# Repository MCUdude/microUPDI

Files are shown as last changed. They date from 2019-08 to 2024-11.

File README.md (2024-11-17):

# microUPDI
DIY UPDI programmer with open-source hardware.
**Available for purchase at my [Tindie store](https://www.tindie.com/products/MCUdude/microupdi-programmer/)!**

## Hardware
The microUPDI programmer is based on the [Sparkfun Pro Micro 5V/16MHz board](https://www.sparkfun.com/products/12640) (cheaper knock-offs also compatible) together with a daughterboard. This makes the programmer both cheap and easy to assemble.

    

## Features
* A 6-pin UPDI programming connector
  - UPDI interface for programming and debugging
  - Serial interface for communicating with the target over UART
* Voltage selection jumper where you can choose between 5V, 3.3V, or no target power
* RXD and TXD LEDs
* Buffered RXD and TXD lines for high-impedance inputs and low-impedance outputs
* Status LED
  - Power up -> LED is briefly lid
  - Normal operation -> LED is not lid
  - Programming -> Activity indicator
* Small in size (18.3mm x 49.6mm)
* **Open source hardware!**

## Firmware
To flash the Pro Micro with mEDBG firmware you'll have to install a hardware package to Arduino IDE.

#### Boards Manager Installation
* Open the Arduino IDE
* Open the **File > Preferences** menu item.
* Enter the following URL in **Additional Boards Manager URLs**:
    ```
    https://mcudude.github.io/microUPDIcore/package_MCUdude_microUPDIcore_index.json
    ```
* Separate the URLs using a comma ( **,** ) if you have more than one URL
* Open the **Tools > Board > Boards Manager...** menu item.
* Wait for the platform indexes to finish downloading.
* Scroll down until you see the **microUPDI flash tool** entry and click on it.
* Make sure you have selected the latest version.
* Click **Install**.
* After installation is complete close the **Boards Manager** window.

#### Manual Installation
Visit [microUPDIcore](https://github.com/MCUdude/microUPDIcore), and click on the "Download ZIP" button. Extract the ZIP file, and move the extracted folder to the location "**~/Documents/Arduino/hardware**". Create the "hardware" folder if it doesn't exist.
Open Arduino IDE and a new category in the boards menu called "microUPDI Firmware Uploader" will show up.

### Flashing the Arduino Pro Micro
* Select **microUPDI Firmware Uploader** from the boards menu.
* Connect your Arduino Pro Micro hardware to your computer through a micro USB cable.
* Click on the upload button. This will upload some pre-built binaries, and the code in the current sketch isn't touched at all.
* The IDE will now automatically try to reset the Pro Micro and load it with new firmware.
  - If you've already flashed your Pro Micro with mEDBG firmware and want to upgrade or re-flash it you will most likely encounter issues with the auto reset functionality and uploading will fail. All you have to do is click *Upload* in Arduino IDE and then manually reset the Pro Micro within about three seconds. Resetting can be done by shorting out pin 5 and 6 on the 32U4 ISP header for a brief second with a tweezer, screwdriver, or jumper wire. If you need a longer timeout delay, you can quickly reset the 32U4 twice. This will make the board stay in bootloader mode for an extended period, usually about 8 seconds. Read more about manual bootloader entry [here](https://learn.sparkfun.com/tutorials/pro-micro--fio-v3-hookup-guide/troubleshooting-and-faq#ts-reset).
* After uploading is finished you may get an error telling you there's **content mismatch from flash address 0x7000**. This is normal and is to be expected due to the protected bootloader area, and the standard Pro Micro bootloader is retained.
* Congratulations, you now have a working UPDI programmer!

### Usage
After the Pro Micro is flashed with mEDBG firmware it will present itself to the computer as an **mEDBG CMSIS-DAP** device. In Atmel Studio it will show up as a generic mEDBG device, while in Arduino IDE it will show up as an **Arduino UNO WiFi Rev2*.

If you're using the microUPDI programmer with [megaTinyCore](https://github.com/SpenceKonde/megaTinyCore) you just select the *Xplained Mini (mEDBG, debug chip: ATmega32u4)* option in the Programmers menu. For [MegaCoreX](https://github.com/MCUdude/MegaCoreX) it's *Atmel mEDBG (microUPDI)*.

Here's an example command on how you can communicate with an ATmega4809 through Avrdude:
```
$ avrdude -C avrdude.conf -v -p atmega4809 -c xplainedmini_updi
```

### Pinout
The UPDI pinout is based on the standard 6-pin ISP pinout. It's reverse insertion tolerant, just like the "old" ISP interface. It's also compatible with the Atmel ICE UPDI pinout. This means if you've designed a board to work with this (microUPDI) programmer, you can safely connect and use an Atmel ICE programmer without damaging your board or the ICE programmer.<br/>
**Note that the RXD and TXD lines are swapped on the target.**

*Click to enlarge:*



### Tinkering with the EEPROM content
The EEPROM content of the microUPDI content contains things like serial number, kit name, manufacturer string, target device ID, and name. The content is loosely documented in [this Avrfreaks forum post](https://www.avrfreaks.net/s/topic/a5C3l000000UkjBEAS/t192342?comment=P-1635680).

<details>
<summary><b>mEDBG EEPROM mapping</b></summary>

```
MEDBG_CONFIG_SERIAL_NUMBER_BANK = 0x00
MEDBG_CONFIG_SERIAL_NUMBER_ADDRESS = 0x04
MEDBG_CONFIG_SERIAL_NUMBER_LEN = 20
 
MEDBG_CONFIG_KIT_NAME_BANK = 0x00
MEDBG_CONFIG_KIT_NAME_ADDRESS = 0x18
MEDBG_CONFIG_KIT_NAME_LEN_MAX = 50
 
MEDBG_CONFIG_MANUFACTURER_NAME_BANK = 0x00
MEDBG_CONFIG_MANUFACTURER_NAME_ADDRESS = 0x4A
MEDBG_CONFIG_MANUFACTURER_NAME_LEN_MAX = 50
 
MEDBG_CONFIG_TARGET_NAME_BANK = 0x00
MEDBG_CONFIG_TARGET_NAME_ADDRESS = 0x7C
MEDBG_CONFIG_TARGET_NAME_LEN_MAX = 30
 
MEDBG_CONFIG_FIRE_BANK = 0x00
MEDBG_CONFIG_FIRE_ADDRESS = 0xFE
MEDBG_CONFIG_FIRE_LEN = 1
 
MEDBG_CONFIG_FIRE_ISPDW_VALUE = 0xFF
MEDBG_CONFIG_FIRE_SWD_VALUE = 0xFE
MEDBG_CONFIG_FIRE_TPI_VALUE = 0XFD
MEDBG_CONFIG_FIRE_UPDI_VALUE = 0xFC
 
MEDBG_CONFIG_SUFFER_BANK = 0x01
MEDBG_CONFIG_SUFFER_ADDRESS = 0x220
MEDBG_CONFIG_SUFFER_LEN = 1
```

</details>

It's very easy to use Avrdude (8.0 or newer is highly recommended) to change the content. Simply connect an ISP programmer, connect it to the ISP connector on the underside of the microUPDI programmer (a 6-pin male header can be press-fitted), and run Avrdude. In the example below I'm using the USBasp programmer with Avrdude 8.0 to view and modify the EEPROM content:

```
$ avrdude -c usbasp -p atmega32u4 -t

avrdude> read eeprom 0 256 # Read 256 bytes from EEPROM starting from address 0
Reading | ################################################## | 100% 0.09 s 
0000  ff ff ff ff 4d 49 43 52  4f 55 50 44 49 50 52 4f  |....MICROUPDIPRO|
0010  47 52 41 4d 4d 45 52 58  6d 69 63 72 6f 55 50 44  |GRAMMERXmicroUPD|
0020  49 20 70 72 6f 67 72 61  6d 6d 65 72 00 ff ff ff  |I programmer....|
0030  ff ff ff ff ff ff ff ff  ff ff ff ff ff ff ff ff  |................|
0040  ff ff ff ff ff ff ff ff  ff ff 4d 69 63 72 6f 63  |..........Microc|
0050  68 69 70 00 ff ff ff ff  ff ff ff ff ff ff ff ff  |hip.............|
0060  ff ff ff ff ff ff ff ff  ff ff ff ff ff ff ff ff  |................|
0070  ff ff ff ff ff ff ff ff  ff ff ff ff 41 54 6d 65  |............ATme|
0080  67 61 34 38 30 39 00 ff  ff ff ff ff ff ff ff ff  |ga4809..........|
0090  ff ff ff ff ff ff ff ff  ff ff 00 1e 96 51 ff ff  |.............Q..|
00a0  ff ff ff ff ff ff ff ff  ff ff ff ff ff ff ff ff  |................|
00b0  ff ff ff ff ff ff ff ff  ff ff ff ff ff ff ff ff  |................|
00c0  ff ff ff ff ff ff ff ff  ff ff ff ff ff ff ff ff  |................|
00d0  ff ff ff ff ff ff ff ff  ff ff ff ff ff ff ff ff  |................|
00e0  ff ff ff ff ff ff ff ff  ff ff ff ff ff ff ff ff  |................|
00f0  ff ff ff ff ff ff ff ff  ff ff ff ff ff ff fc ff  |................|

avrdude> write eeprom 4 20 0xff ... # Wipe the existing serial number by writing 20 0xff bytes to the EEPROM, starting from address 4
Caching | ################################################## | 100% 0.00 s

avrdude> read eeprom 0 256
Reading | ################################################## | 100% 0.00 s 
0000  ff ff ff ff ff ff ff ff  ff ff ff ff ff ff ff ff  |................|
0010  ff ff ff ff ff ff ff ff  6d 69 63 72 6f 55 50 44  |........microUPD|
0020  49 20 70 72 6f 67 72 61  6d 6d 65 72 00 ff ff ff  |I programmer....|
0030  ff ff ff ff ff ff ff ff  ff ff ff ff ff ff ff ff  |................|
0040  ff ff ff ff ff ff ff ff  ff ff 4d 69 63 72 6f 63  |..........Microc|
0050  68 69 70 00 ff ff ff ff  ff ff ff ff ff ff ff ff  |hip.............|
0060  ff ff ff ff ff ff ff ff  ff ff ff ff ff ff ff ff  |................|
0070  ff ff ff ff ff ff ff ff  ff ff ff ff 41 54 6d 65  |............ATme|
0080  67 61 34 38 30 39 00 ff  ff ff ff ff ff ff ff ff  |ga4809..........|
0090  ff ff ff ff ff ff ff ff  ff ff 00 1e 96 51 ff ff  |.............Q..|
00a0  ff ff ff ff ff ff ff ff  ff ff ff ff ff ff ff ff  |................|
00b0  ff ff ff ff ff ff ff ff  ff ff ff ff ff ff ff ff  |................|
00c0  ff ff ff ff ff ff ff ff  ff ff ff ff ff ff ff ff  |................|
00d0  ff ff ff ff ff ff ff ff  ff ff ff ff ff ff ff ff  |................|
00e0  ff ff ff ff ff ff ff ff  ff ff ff ff ff ff ff ff  |................|
00f0  ff ff ff ff ff ff ff ff  ff ff ff ff ff ff fc ff  |................|

avrdude> write eeprom 4 "MYSERIALNUMBER" # Write new serial number to EEPROM, starting from address 4
Caching | ################################################## | 100% 0.00 s

avrdude> read eeprom 0 256
Reading | ################################################## | 100% 0.00 s 
0000  ff ff ff ff 4d 59 53 45  52 49 41 4c 4e 55 4d 42  |....MYSERIALNUMB|
0010  45 52 00 ff ff ff ff ff  6d 69 63 72 6f 55 50 44  |ER......microUPD|
0020  49 20 70 72 6f 67 72 61  6d 6d 65 72 00 ff ff ff  |I programmer....|
0030  ff ff ff ff ff ff ff ff  ff ff ff ff ff ff ff ff  |................|
0040  ff ff ff ff ff ff ff ff  ff ff 4d 69 63 72 6f 63  |..........Microc|
0050  68 69 70 00 ff ff ff ff  ff ff ff ff ff ff ff ff  |hip.............|
0060  ff ff ff ff ff ff ff ff  ff ff ff ff ff ff ff ff  |................|
0070  ff ff ff ff ff ff ff ff  ff ff ff ff 41 54 6d 65  |............ATme|
0080  67 61 34 38 30 39 00 ff  ff ff ff ff ff ff ff ff  |ga4809..........|
0090  ff ff ff ff ff ff ff ff  ff ff 00 1e 96 51 ff ff  |.............Q..|
00a0  ff ff ff ff ff ff ff ff  ff ff ff ff ff ff ff ff  |................|
00b0  ff ff ff ff ff ff ff ff  ff ff ff ff ff ff ff ff  |................|
00c0  ff ff ff ff ff ff ff ff  ff ff ff ff ff ff ff ff  |................|
00d0  ff ff ff ff ff ff ff ff  ff ff ff ff ff ff ff ff  |................|
00e0  ff ff ff ff ff ff ff ff  ff ff ff ff ff ff ff ff  |................|
00f0  ff ff ff ff ff ff ff ff  ff ff ff ff ff ff fc ff  |................|

avrdude> quit
Synching cache to device ... 
Writing | ################################################## | 100% 0.04 s 

Avrdude done.  Thank you.
```

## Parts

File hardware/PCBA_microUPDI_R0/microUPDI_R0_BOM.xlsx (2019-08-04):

Bill of Materials
Author: | MCUdude
Source from: | microUPDI.PrjPcb
Project name: | microUPDI.PrjPcb
Variant: | None
Revision: | R0
Creation date: | 04.08.2019
Quantity | Designator | Value | Manufacturer | Manufacturer Part Number | Manufacturer 2 | Manufacturer Part Number 2 | Description | Package | Notes
2 | C1, C2 | 1u |  |  |  |  | Cap Ceramic 0805 1u 16V Y5V | 0805 | Generic, choose one that meets spec
2 | C3, C4 | 100n |  |  |  |  | Cap Ceramic 0805 100n 50V X7R | 0805 | Generic, choose one that meets spec
1 | D1 |  |  |  |  |  | LED 0805 Green | 0805
2 | D2, D3 |  |  |  |  |  | LED 0805 Red | 0805
1 | IC1 |  |  | 1117-3.3 |  |  | Positive 3.3V regulator 1A SOT-223 | SOT-223 | Generic 1117-3.3
2 | IC3, IC4 |  |  | 74LVC1G125 |  |  | Singe Buffer with 3-State Output | SOT-353
1 | J1 |  |  |  |  |  | Header male straight 1x3
1 | J2 |  |  |  |  |  | Header male straight 2x3
3 | R1, R2, R5 | 1k |  |  |  |  | Resistor 0805 1k 1% | 0805 | Generic, choose one that meets spec
1 | R3 | 330R |  |  |  |  | Resistor 0805 330R 1% | 0805 | Generic, choose one that meets spec
1 | R4 | 10k |  |  |  |  | Resistor 0805 10k 1% | 0805 | Generic, choose one that meets spec

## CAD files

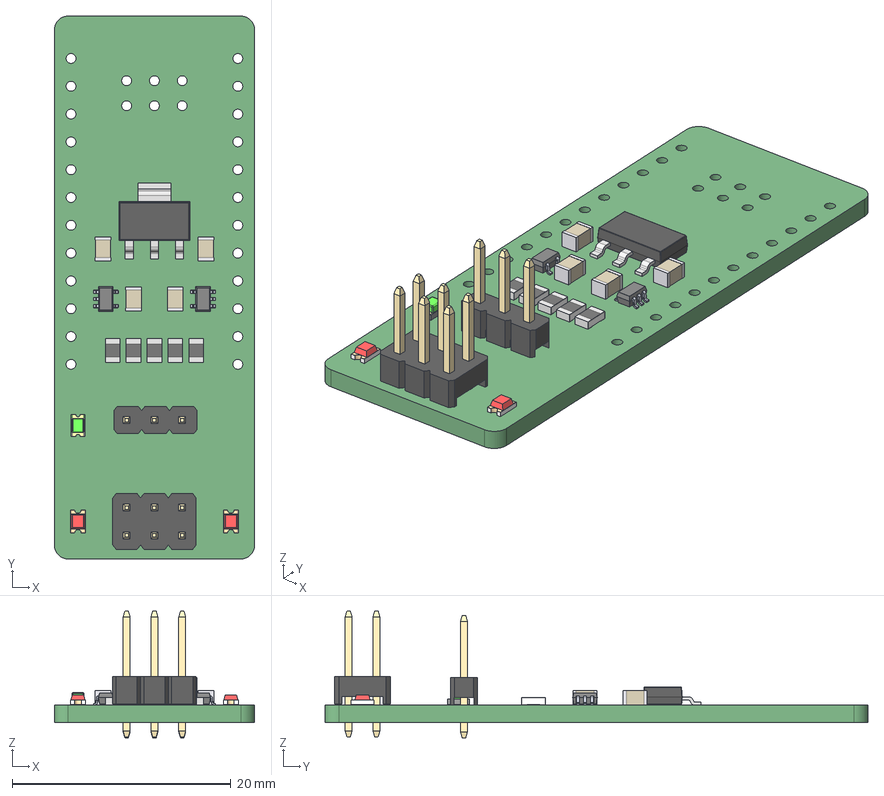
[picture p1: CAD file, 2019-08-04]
hardware/PCBA_microUPDI_R0/microUPDI_R0_STEP_3D_model.step
18.3 x 49.6 x 11.6 mm
Board
RES_0805_(2012_metric) x 5
Header-male-straight-2x3
SOT353-1 x 2
LED-0805-red x 2
LED-0805-green
CAP_0805 x 4
SOT-223
Header-male-straight-1x3

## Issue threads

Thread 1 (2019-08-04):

Flash Pro micro with mEDBG firmware using its USB connector and Arduino IDE

MCUdude, 2019-08-04:
I'm sure this can be done very elegantly by providing a bare minimum Arduino core with a boards manager URL. Would you like to contribute to this @per1234

per1234, 2019-08-04:
>The default auto reset function (1200 baud hack) takes quite a bit of time. How do we deal with this when this can last longer than the bootloader timeout? A separate menu option in the tools menu for first time program and firmware upgrade?

I'm not sure I understand. The Arduino IDE's ATmega32U4 "1200bps_touch" feature waits some time for a new port to appear, but as soon as the new port appears (which happens as soon as you manually reset the board), it immediately runs the avrdude command.

---
I'm having an avrdude verification failure of the second write operation. Interestingly, the verification of the flash write fails if that's the second operation in the command, the verification of the .eep fails if that's the second operation in the command. The verification of the first operation always succeeds. From a quick test of only a few EEPROM values, it looks like the correct values are getting written. Do you have any ideas about that? Are you having any problems like that?

Another thing of interest: I noticed that if I try to run your avrdude command: `-Ueeprom:w:mEDBG_UPDI_1.13.eep`, it fails with:
```
invalid file format 'mEDBG_UPDI_1.13.eep' in update specifier
```
I am specifying the Intel hex file format in my avrdude command: `-Ueeprom:w:mEDBG_UPDI_1.13.eep:i`. Is that correct?

per1234, 2019-08-04:
>it fails with:
```
invalid file format 'mEDBG_UPDI_1.13.eep' in update specifier
```
I think this is a Windows-specific problem. I didn't provide my actual command:
```
tools.avrdude.upload.pattern="{cmd.path}" "-C{config.path}" {upload.verbose} {upload.verify} -p{build.mcu} -c{upload.protocol} "-P{serial.port}" -b{upload.speed} -D -Ueeprom:w:"{runtime.platform.path}/firmware/mEDBG_firmware/mEDBG_UPDI_1.13.eep" -Uflash:w:"{runtime.platform.path}/firmware/mEDBG_firmware/mEDBG_UPDI_1.13.hex":i
```
This specifies the full path to the .eep file, which contains "c:", so that provides the first colon avrdude expects in the command. I was hoping that quoting the path would fix that, but no luck. Well, It's no problem now that I understand the cause. I just need to specify the format, even if that is `a` for the default input file format.

MCUdude, 2019-08-04:
> The Arduino IDE's ATmega32U4 "1200bps_touch" feature waits some time for a new port to appear, but as soon as the new port appears (which happens as soon as you manually reset the board), it immediately runs the avrdude command.

You're right! I just assumed is were like this. By manually toggling reset the upload starts immediately.

EEPROM upload works fine here, given that EEPROM is flashed before the flash memory.
A verification mismatch on address 0x7000 is to be expected because the mEDBG hex file also contains a similarly sized bootloader that can't be written.

```
avrdude: verifying ...
avrdude: verification error, first mismatch at byte 0x7000
         0x55 != 0x0c
avrdude: verification error; content mismatch
```

per1234, 2019-08-04:
OK, I'm getting the verification error of the .hex file at 0x7000 and no verification error of the .eep file as long as I write the .eep first, then the .hex, so I'll not worry about that. This will currently cause the Arduino IDE to report the upload as a failure if people have verification enabled in preferences (which is the default). Should I configure the upload command to never verify, or is it possible to modify the firmware .hex file so that it doesn't try to write to the boot section?

MCUdude, 2019-08-04:
It's a nice thing to know that the verification error occurred at 0x7000. That tells us that the rest of the firmware is fine.

It _is_ possible to modify the mEDBG hex file and remove the bootloader part in order for the verification to succeed, but then I'll have to manually do this every time there's a new mEDBG firmware available.

I also want to keep the existing loader scripts with the default firmware. By using these the microUPDI programmer will software vise be a 100% "real" mEDBG with the original bootloader, and the firmware can be updated through Atmel Studio.

per1234, 2019-08-04:
OK, I understand. To avoid the spurious upload failure, I should be able to make a wrapper script/batch file for avrdude that will suppress the exit status 1 only when it detects the line in the output:
```
avrdude: verification error, first mismatch at byte 0x7000
```
I'm sure I can do this fairly easily in a shell script, but doing anything complex in a batch file is usually more difficult than it has any reason to be.

MCUdude, 2019-08-04:
It isn't necessarily a bad thing to have the error message shown. If you're baking a batch script it's also important to make sure it's supported on Mac an Linux as well.

MCUdude, 2019-08-04:
How about the script outputs something like "DFU bootloader not written" or something similar when the 0x7000 error is detected? It is nice to know what worked and what didn't in an upload sequence.

per1234, 2019-08-04:
>If you're making a batch script it's also important to make sure it's supported on Mac an Linux as well.

Of course. The Arduino hardware system allows you to specify a different property for each OS. So I can do things like this:
```
# Used on Linux and macOS
tools.avrdude.cmd.path={path}/scripts/avrdudewrapper.sh
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
per1234, 2019-08-05:
Sounds good.

MCUdude, 2019-08-07:
I'll receive some microUPDI PCBs at the beginning of next week. I'll do some testing with it before we I do a microUPDIcore release (for boards manager).

MCUdude, 2019-08-15:
I've received some microUPDI boards, and they work great! Maybe we can do a microUPDIcore release so that boards manager install is possible?

per1234, 2019-08-15:
Sounds good. I'm ready to do the Boards Manager thing whenever you are.

Are you going to have microUPDI boards for sale? I definitely want to buy one when available.

MCUdude, 2019-08-15:
> Sounds good. I'm ready to do the Boards Manager thing whenever you are.

Great! Is there anything I'll have to do before you can submit a PR? make a gh-pages branch maybe?

> Are you going to have microUPDI boards for sale? I definitely want to buy one when available.

I am. I only have four boards left, but I'll see if I can add them to Tindie soon. To keep shipping cost down I'm planning to only solder the SMD parts, and leave the UPDI and target voltage header for the user to solder. What do you think is a fair price for a board with all the SMD components on,  1x3 pin target voltage header, jumper, and a 2x3 pin UPDI header?
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

per1234, 2019-08-15:
>make a gh-pages branch maybe?

That's correct. I figure we can do it just like the other cores since that seems to work well.

>To keep shipping cost down I'm planning to only solder the SMD parts, and leave the UPDI and target voltage header for the user to solder.

Sounds good!

>What do you think is a fair price

I have no clue because I don't know all the parts, labor, and overhead costs.

For my glass work, I have a nice spreadsheet set up where I can input the materials cost, production time, and failure rate and it automatically calculates what I need to charge to cover materials and overhead cost as well as getting paid for my time. I just let the spreadsheet make the pricing decision rather than trying to figure out what people are willing to pay for the product. I put it on the market at that price and if it sells then it's a viable product.

It gets tricky trying to figure out how to distribute NRE costs though. If you had to charge enough on the first board to cover all the development and design time you spent, that would be a pricey board indeed! I have product development time and expense items in my overhead calculation that are really just a rough estimate of an average of how much I spend developing products. It's certainly not a perfect system but I think it averages out to be fairly accurate across many products.

The problem is that setting that whole system up in the first place and then gathering the data for each new product is a lot of work and somewhat boring. For this reason, a lot of my fellow glassblowers just sort of pull a price out of the air, but I think this is a dangerous thing to do. That practice is especially hazardous when it comes to production work, where if you set the price unnecessarily high the resellers will have trouble moving the product and not come back for a re-order, but if you set the price too low you end up making no profit on a large sale and having friction when you later try to raise the price on the next order from the buyer.

MCUdude, 2019-08-16:
`gh-pages` branch created!

> I have no clue because I don't know all the parts, labor, and overhead costs.

True. I spent some time trying to get the mEDBG firmware to work on custom hardware before I figured out I had to tie the AREF pin to VCC in order for it to actually work. I also spent some time designing the hardware, but this wasn't particularly difficult. For a start, I'm thinking somewhere between $10 and $15 + shipping (~$4). That will cover the cost, labor, and handling. Compared to a small board from China it's quite expensive, but I can never compete with their prices. I can, however, compete by providing good documentation and an easy-to-use solution.

MCUdude, 2019-08-21:
@per1234 anything else you need to create a boards manager URL? I've also [released v1.0.0](https://github.com/MCUdude/microUPDIcore/releases).

MCUdude, 2019-08-31:
Good point! I'll add a note to the *Usage* section in the README.

I'll hope you'll find the microUPDI board useful! I sold all four boards in less than 24 hours, so there is some demand I guess. I'll try to make more board as quickly as I can. If this pinout is going to be the new "UPDI" standard It's important that as many people as possible can get one if they need one.

Closed 2019-08-31.

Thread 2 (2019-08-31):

Pro Micro hardware modification clarification

hiduino, 2019-08-31:
Can you clarify the hardware modification?  It appears that pin-1 (in the picture example) of the regulator is the RAW input, not the 5V output pin.

MCUdude, 2019-08-31:
It is indeed connected to the VIN pin, However, since microUPDI requires a 5V 16 MHz Pro Mini, this means that the solder jumper (SJ1 in the [Pro Micro schematics](https://cdn.sparkfun.com/datasheets/Dev/Arduino/Boards/Pro_Micro_v13b.pdf) is shorted, and ~4.5V will appear on the VIN pin.

I chose that connection point because it's the closest to the AREF capacitor. However, you may choose any 5V point on the board if you like.

hiduino, 2019-08-31:
Yes, thanks for the clarification.  I think it will be safer to go with the 5V output, just in case someone decides to put in more than 5.5V on the raw input (not that anyone would but you never know).

MCUdude, 2019-08-31:
> I think it will be safer to go with the 5V output, just in case someone decides to put in more than 5.5V on the raw input (not that anyone would but you never know).

There's no reason to connect the Raw pin to anything when using the Pro Micro as a UPDI programmer. I'll leave a note that the Raw pin shouldn't be used.

MCUdude, 2020-10-19:
The latest release (v1.0.1) uses a modified firmware where the hardware modification is no longer necessary since AREF is connected to VCC internally instead

Closed 2020-10-19.

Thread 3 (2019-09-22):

Create a 12V version of microUPDI

MCUdude, 2019-09-22:
I'm planning to make a 12V version of this programmer. This will allow users to program chips that's had their UPDI line turned into a GPIO pin.

This version will be physically larger than the non-12V version due to increased component count.

We can generate a 12V rail by attaching a diode/capacitor voltage multiplier to the 16 MHz clock output. The frequency should preferably have been lower, but the mEDBG firmware is very limited when it comes to customizability, so that's all we got.

The AVR is very picky when it comes to the 12V pulse. According to sources over at the Avrfreaks forum, the 12V pulse should be between 500 and 1000us long, before puled low for about 100 seconds. This can be accomplished with some careful MOSFET circuitry.

MCUdude, 2019-09-24:
Here's what I've come up with so far. The pulse generator hasn't been tested on an actual ATtiny yet, but I will do that very soon. @SpenceKonde how long did you have to keep the UPDI line low after the 12V pulse? I also want to keep @westfw in the loop since he is actively working on Optiboot support for this chip family.

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

WestfW, 2019-09-25:
Seems like a lot of stages in the voltage multiplier.  I got nearly 15 V from an Arduino 50% PWM output, using of a total of 4 diodes with:
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

MCUdude, 2019-09-25:
> Seems like a lot of stages in the voltage multiplier.

I know. I initially was planning to use only four diodes, but I only got a 10V output when driving the multiplier with 5V. With six diodes I got a voltage close to 15V. It's then clamped by a 12V zener.

I've done some more tests on my ATtiny817 Xplained mini. Seems like it doesn't matter if the UPDI line is pulled low or left high-Z after the 12V pulse have been injected. This means we can simplify the pulse generator design a lot.

However, the Q1A MOSFET should probably be driven directly by a 74LVC1G125, since this buffer has a push-pull output that will prevent the output from having a slope due to the capacitor discharge.

mraardvark, 2019-09-25:
More info on the "updated" high-voltage UDI activation:
https://www.avrfreaks.net/comment/2616176#comment-2616176
(Cross-posting from freaks.)

MCUdude, 2019-09-25:
> [from Avrfreaks]  If a KEY is not received within 65ms the device will continue operation as normal reset, and the pin will go back to it's non-UPDI configuration.

There doesn't seem to be a 65 ms timeout, at least not on the ATtiny817. The microcontroller is still running its program after the 12V pulse, but I am able to communicate with it over the UPDI interface, meaning that the GPIO/RST pin is temporarily converted to the UDPI pin until the next power cycle. I also found some good information in chapter 33.3.2.2 in the ATtiny417/817/1617/3217 datasheet.

Same result when pulling the line down to ground or leaving it high-Z after the 12V pulse. @mraardvark have you tried reviving a tiny0/tiny1 chip with a 12V pulse?

mraardvark, 2019-09-25:
Updi on newer parts is not the same as the original 817 - as the freaks posting says, the documentation is severely lagging the silicon :/
A 'new' 3217 definitely just resets when given a blind 12v spike. You should probably broaden your sample collection before going out on this limb...
(I guess the 817s mounted on the minis are all 'old')

WestfW, 2019-09-25:
Did you see the part in the datasheets (416, 3217) how the 12V "enable updi sequence" is permanent till the next power cycle?  It's not clear how far into the sequence you have to get for this to be the case...

> When enabled by 12V, only a POR will disable the UPDI configuration on the RESET pin, and restore the default setting. If issuing a UPDI disable command through the UPDIDIS bit in UPDI.CTRLB, the UPDI will be reset and the clock request will be canceled, but the RESET pin will remain in UPDI configuration.

MCUdude, 2019-09-25:
I just finished working with this for the evening. It's super easy to recover an ATtiny817. However, some ATtinys seems to have much more strict rules when it comes to timing. I turned the UPDI line into a GPIO on at ATtiny1616, and I have not been able to recover it by manually applying 12V, or using a pulse generator. At this point, I don't know how I can recover it. I tried to time the 12V pulse as best as I could (using a scope to monitor the UPDI line), but I always got a 0x02 or 0x04 error from Atmel Studio.

Does anybody know if someone has been able to reliably recover "new tiny-1" chips, such as my ATtiny1616? If so, I'm interested to know what hardware they use. Maybe we'll have to use a dedicated microcontroller to control the 12V pulse and inject the KEY at the exact same time?

Bottom line: The "new" 12V UPDI interface is a pain in the ass.

SpenceKonde, 2019-09-25:
Hm, it was a 1616 that I unbricked with the 500us 12v pulse followed by pulling the line low. It did *not* work when the line was returned to 5v instead of 0v after the 12v pulse, though.

mraardvark, 2019-09-26:
On the 'old' 817 an ESD event on the UPDI line when used as GPIO would potentially enable UPDI and leave the application stranded without that GPIO.  In an industrial product that would not be acceptable, would it?

MCUdude, 2019-09-26:
> On the 'old' 817 an ESD event on the UPDI line when used as GPIO would potentially enable UPDI and leave the application stranded without that GPIO. In an industrial product that would not be acceptable, would it?

That's true. But it makes it way more difficult for amateurs like me to enter programming mode again. I don't know the UPDI protocol very well, but maybe we could a small micro such as ATtiny202/212 to send the KEY after the 12V pulse is injected? I will assume the target won't time out after the key is received; am I right?

If so, we could make a pulse generator + "key injector" based around a voltage multiplier (to generate 12V) and a small microcontroller. By using a tiny0/tiny1 we can easily reprogram it by connecting its UPDI line to the mEDBG chip using a jumper.

MCUdude, 2019-10-05:
I've been able to compile a stripped-down version of JTAG2UPDI to run on an ATtiny13. The JTAG2UPDI code isn't compatible with the new tiny0/tiny1 series, so I decided to use an older AVR instead. I _could_ use an ATtiny25, but the ATtiny13 is cheaper and has enough memory for this application.

The ATtiny13 can be driven from a 16 MHz clock output from the ATmega32u4, or from its internal 9.6 MHz oscillators (if it turns out to be accurate enough). The program flow will look like this:

```c++
while(1)
{
  // Button pressed
  if((PINB & _BV(PB2)) == 0)
  {
    // Poor mans debounce
    while((PINB & _BV(PB2)) == 0)
      _delay_ms(250);

    // Inject 12V pulse
    PORTB |= _BV(PB4);
    _delay_us(650);
    PORTB &= ~_BV(PB4);

    // Inject NVMPROG key
    JTAG2::enter_progmode();

    // Prevent double clicks
    _delay_ms(2000);
  }
}
```

MCUdude, 2019-12-04:
Here's something I'd like to make a prototype of. It's based on the JTAG2UPDI project but will send a 12V pulse followed by an NVMPROG key to enable the reset line. The target can be powered from either 5 or 3.3V. By switching the MODE switch you can use the programmer as a regular USB to serial adapter with a DTR/RTS like for Optiboot auto-reset. The board itself measures 24x44mm.

Thoughts @SpenceKonde ?

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

WestfW, 2019-12-05:
I am hoping to see a working 12V UPDI programmer out of Microchip before I think too much about implementing one myself.  Apparently datasheets are vague, newer chips may behave differently that older chips, and ... nothing does it yet :-(

MCUdude, 2019-12-05:
> I am hoping to see a working 12V UPDI programmer out of Microchip before I think too much about implementing one myself. Apparently datasheets are vague, newer chips may behave differently than older chips, and ... nothing does it yet :-(

The only programmer I'm aware of that supposedly supports 12V is the power debugger. What I already know is that "old" chips (like the one on my 817 Xplained Mini) only need a 12V pulse, while newer chips (like my 1616 Xplained Nano) need the NVMPROG key, followed by a reset command.

But I don't see why the board above shouldn't work apart from potential electric errors?

MCUdude, 2019-12-05:
Here's the schematic for it BTW:
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

WestfW, 2019-12-05:
I don't see 3.3V/5V for RTS/DTR on the UPDI connector?
Is the analog multiplexer fast enough for the serial data rates people expect these days?

MCUdude, 2019-12-05:
> I don't see 3.3V/5V for RTS/DTR on the UPDI connector?

That's something I forgot to add. Will look into this. BTW would it even be a problem to have a 5V DTR pulse on a 3.3V powered target? The RST/UPDI pin does not have the same protection diodes as other pins do, but it shouldn't cause damage or accidentally trigger programming mode on "older" Xtinys, since the voltage is way lower than VCC/2?

> Is the analog multiplexer fast enough for the serial data rates people expect these days?

It has a rated bandwidth of 17 MHz. Should be plenty for your average 115200 stuff. I chose this because I literally have a pile of them.

MCUdude, 2020-10-19:
I abandoned this project because I have better things to do, and it turned out to be trickier than I initially thought.

Closed 2020-10-19.

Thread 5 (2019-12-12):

Clone microUPDI not working

EclipseBoom, 2019-12-12:
Hi Hans,

I built a clone PCB of your design except I changed the 5V/3.3V buffer to a 74LVC1T45 for the serial port (not using at this point).  I did the AREF modification on the Micro.   Flashed the uUPDI core code fine.

Arduino IDE won't program with the unit.  Atmel Studio 7.0 sees the UPDI programmer but only allows ATMega4809 chips.  If I try to ID the chip it sees my chip ATTiny816 but won't allow me to program it since it is not a 4809.

Also, tried FLASHing the Mega32u4 manually using the .hex files.  Same behavior.  Working on Windows 7 64-bit.  Any ideas?

MCUdude, 2019-12-13:
> I built a clone PCB of your design except I changed the 5V/3.3V buffer to a 74LVC1T45 for the serial port (not using at this point). I did the AREF modification on the Micro. Flashed the uUPDI core code fine.

Awesome, would you like to post a picture of it? The LVC1T45 is probably even better for this than LVC1G125, but I used this because I literally have a pile of them after getting loads of free components on rolls from a former college.

> Arduino IDE won't program with the unit. Atmel Studio 7.0 sees the UPDI programmer but only allows ATMega4809 chips. If I try to ID the chip it sees my chip ATTiny816 but won't allow me to program it since it is not a 4809.

Have you tried with Avrdude? Before I figured out the AREF mod it did work with Atmel Studio 7, but not with Avrdude.
When it comes to the actual firmware this is pulled off an Arduino Uno Wifi Rev2, because this was the newest mEDBG version I was able to retrieve (1.13). This chip is probably set up to only work with ATmega4809 by default since this should be the only target if used on an Uno Wifi Rev2. I don't remember exactly where, but somewhere in the settings, you can choose to show all "compatible" chips for the connected programmer, not just the default one. IIRC I did this on my work computer.

EclipseBoom, 2019-12-13:
Thanks for the pointer. In Atmel Studio under Options->Tools->Tool settings you can set the option "Hide unsupported devices" to FALSE and then the full list of AVR parts shows up.

The programming and verify works.  Yay!!!!

Attached are some images of my unit.

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

EclipseBoom, 2019-12-13:
Regarding the Arduino IDE.  When Onboard Atmel eEDBG ... (megaTinyCore) is chosen as the programmer and the same connection to the target is used.  I get the following error messages:

It looks to me like the AVRDude configuration is not correct since the ATTiny816 does indeed have a UPDI interface.

`Arduino: 1.8.10 (Windows 7), Board: "ATtiny3216/1616/1606/816/806/416/406, ATtiny816, 20 MHz, 1.8V, Disabled, Disabled, EEPROM retained, 0.55V, Enabled, PORTA (pins 0~3,14~17), TX:14, RX:15, SDA:8, SCL:9, SCK:10, MISO:11, MOSI:12"

Sketch uses 2438 bytes (29%) of program storage space. Maximum is 8192 bytes.
Global variables use 97 bytes (18%) of dynamic memory, leaving 415 bytes for local variables. Maximum is 512 bytes.
C:\Users\Chris\AppData\Local\Arduino15\packages\arduino\tools\avrdude\6.3.0-arduino17/bin/avrdude -CC:\Users\Chris\AppData\Local\Arduino15\packages\megaTinyCore\hardware\megaavr\1.1.2/avrdude.conf -v -pattiny816 -cxplainedmini_updi -Pusb -Uflash:w:C:\Users\Chris\AppData\Local\Temp\arduino_build_433361/ircomm_test.ino.hex:i

avrdude: Version 6.3-20190619
         Copyright (c) 2000-2005 Brian Dean, http://www.bdmicro.com/
         Copyright (c) 2007-2014 Joerg Wunsch

         System wide configuration file is "C:\Users\Chris\AppData\Local\Arduino15\packages\megaTinyCore\hardware\megaavr\1.1.2/avrdude.conf"

         Using Port                    : usb
         Using Programmer              : xplainedmini_updi
avrdude: Found CMSIS-DAP compliant device, using EDBG protocol
         AVR Part                      : ATtiny816
         Chip Erase delay              : 0 us
         PAGEL                         : P00
         BS2                           : P00
         RESET disposition             : dedicated
         RETRY pulse                   : SCK
         serial program mode           : yes
         parallel program mode         : yes
         Timeout                       : 0
         StabDelay                     : 0
         CmdexeDelay                   : 0
         SyncLoops                     : 0
         ByteDelay                     : 0
         PollIndex                     : 0
         PollValue                     : 0x00
         Memory Detail                 :

                                  Block Poll               Page                       Polled
           Memory Type Mode Delay Size  Indx Paged  Size   Size #Pages MinW  MaxW   ReadBack
           ----------- ---- ----- ----- ---- ------ ------ ---- ------ ----- ----- ---------
           signature      0     0     0    0 no          3    0      0     0     0 0x00 0x00
           prodsig        0     0     0    0 no         61   61      0     0     0 0x00 0x00
           fuses          0     0     0    0 no          9    0      0     0     0 0x00 0x00
           fuse0          0     0     0    0 no          1    0      0     0     0 0x00 0x00
           fuse1          0     0     0    0 no          1    0      0     0     0 0x00 0x00
           fuse2          0     0     0    0 no          1    0      0     0     0 0x00 0x00
           fuse4          0     0     0    0 no          1    0      0     0     0 0x00 0x00
           fuse5          0     0     0    0 no          1    0      0     0     0 0x00 0x00
           fuse6          0     0     0    0 no          1    0      0     0     0 0x00 0x00
           fuse7          0     0     0    0 no          1    0      0     0     0 0x00 0x00
           fuse8          0     0     0    0 no          1    0      0     0     0 0x00 0x00
           lock           0     0     0    0 no          1    0      0     0     0 0x00 0x00
           data           0     0     0    0 no          0    0      0     0     0 0x00 0x00
           usersig        0     0     0    0 no         32   32      0     0     0 0x00 0x00
           flash          0     0     0    0 no       8192   64      0     0     0 0x00 0x00
           eeprom         0     0     0    0 no        128   32      0     0     0 0x00 0x00

         Programmer Type : JTAGICE3_UPDI
         Description     : Atmel AVR XplainedMini in UPDI mode
         ICE hardware version: 0
         ICE firmware version: 1.19 (rel. 57)
         Serial number   : MICROUPDIPROGRAMMERX
         Vtarget         : 5.00 V
         JTAG clock megaAVR/program: 0 kHz
         JTAG clock megaAVR/debug:   0 kHz
         JTAG clock Xmega: 0 kHz
         PDI clock Xmega : 0 kHz

avrdude: jtag3_initialize(): part ATtiny816 has no UPDI interface
avrdude: initialization failed, rc=-1
         Double check connections and try again, or use -F to override
         this check.

avrdude done.  Thank you.

An error occurred while uploading the sketch

This report would have more information with
"Show verbose output during compilation"
option enabled in File -> Preferences.
`

EclipseBoom, 2019-12-13:
I think I got it.  In avrdude.conf  at line 15210 there is:

```
part
    id		= ".avr8x";
    desc	= "AVR8X family common values";
#    has_updi	= yes;
    has_pdi	= yes;
    nvm_base	= 0x1000;
#    ocd_base	= 0x0F80;

```
Change to:

```
part
    id		= ".avr8x";
    desc	= "AVR8X family common values";
    has_updi	= yes;
#    has_pdi	= yes;
    nvm_base	= 0x1000;
#    ocd_base	= 0x0F80;

```
And it programs and verifies.  Yay!!! At least for the Tiny816 and Tiny402 chips I tried.  Don't know if this is a full solution - I'm not an avrdude.conf guy.

MCUdude, 2019-12-13:
Great looking hardware! Almost as good as mine! 😄

Great to hear you figured it out. If you believe there's a bug in the megaTinyCore, you should definitely report it there, so it can be fixed properly.

MCUdude, 2019-12-14:
I was just thinking about how Atmel Studio could identify that this particular mEDBG firmware should be default only be able to use used with ATmega4809.

After a bit of investigation it turns out that the 4809 device signature (1E 96 53) is actually [burned into the EEPROM](https://github.com/MCUdude/microUPDIcore/blob/f5c20418ca8572356122b39f8d53cf9c319c58b7/avr/firmwares/mEDBG_UPDI_1.13_modified_suffer.eep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). I don't have time to test this theory at the moment, but I think Atmel studio will detect it as a generic mEDBG if these three bytes was set to 00 00 00 or FF FF FF. All you need to do is to change the values in the .eep file and calculate the 8-bit checksum at the end.

mraardvark, 2019-12-16:
The information in the EEPROM on the mEDBG is only for Studio to populate the device selection drop-down.  If you go into Studio options and un-check "hide unsupported devices" then the full device selection list is made available.

EclipseBoom, 2019-12-16:
> The information in the EEPROM on the mEDBG is only for Studio to populate the device selection drop-down. If you go into Studio options and un-check "hide unsupported devices" then the full device selection list is made available.

Ideally what we want is for Atmel Studio to auto populate that dropdown with all UPDI programmable devices.

EclipseBoom, 2019-12-16:
> I was just thinking about how Atmel Studio could identify that this particular mEDBG firmware should be default only be able to use used with ATmega4809.
>
> After a bit of investigation it turns out that the 4809 device signature (1E 96 53) is actually [burned into the EEPROM](https://github.com/MCUdude/microUPDIcore/blob/f5c20418ca8572356122b39f8d53cf9c319c58b7/avr/firmwares/mEDBG_UPDI_1.13_modified_suffer.eep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). I don't have time to test this theory at the moment, but I think Atmel studio will detect it as a generic mEDBG if these three bytes was set to 00 00 00 or FF FF FF. All you need to do is to change the values in the .eep file and calculate the 8-bit checksum at the end.

So I tried changing these to all 00 00 00 or FF FF FF with the correct checksum and there is no change.  Studio still only offers the Mega4809 with "Hide Unsupported" set as TRUE.  Bummer.

Note, the tool does correctly find the chip that is attached.  An reading the device sig does work.  But with "Hide unsupported" as TRUE the software won't enter programming mode.

Closed 2019-12-13.

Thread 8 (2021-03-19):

Flashing firmware times out, then bricks board

maxgerhardt, 2021-03-19:
Using a brand new Pro Micro 5V board [from here](https://eckstein-shop.de/HIMALAYA-Basic-Pro-Micro-5V-16MHz-Arduino-Mini-Leonardo-Compatible-board), plugging it into the computer and following the instructions from [here](https://github.com/MCUdude/microUPDI#flashing-the-arduino-pro-micro) give me a timeout after maybe 60 seconds.

```
Der Sketch verwendet 0 Bytes (0%) des Programmspeicherplatzes. Das Maximum sind 28672 Bytes.
Globale Variablen verwenden 0 Bytes (0%) des dynamischen Speichers, 2560 Bytes für lokale Variablen verbleiben. Das Maximum sind 2560 Bytes.
Erzwinge Reset durch öffnen/schließen mit 1200 bps auf dem Port COM30
PORTS {COM1, COM30, } / {COM1, } => {}
PORTS {COM1, } / {COM1, } => {}
PORTS {COM1, } / {COM1, COM31, } => {COM31, }
Found upload port: COM31
C:\Users\Max\AppData\Local\Arduino15\packages\microUPDIcore\hardware\avr\1.0.1/scripts/avrdude-wrapper.bat C:\Users\Max\Desktop\Programming Stuff\arduino-1.8.13\hardware\tools\avr/bin/avrdude C:\Users\Max\Desktop\Programming Stuff\arduino-1.8.13\hardware\tools\avr/etc/avrdude.conf atmega32u4 avr109 COM31 57600 C:\Users\Max\AppData\Local\Arduino15\packages\microUPDIcore\hardware\avr\1.0.1 C:\Users\Max\AppData\Local\Temp\arduino_build_545881
Beim Hochladen des Sketches ist ein Fehler aufgetreten
```

The lines saying
```
Sketch uses 0 Bytes of program memory. The maximium is 28672 bytes.
Global variables use 0 Bytes..
Forcing reset by opening/closing at 1200bps on COM30
[...]
Found upload port: COM31
[command]
An error occured while uploading the sketch.
```
^After that I still have COM31 but consequent upload attempts yield

```
Erzwinge Reset durch öffnen/schließen mit 1200 bps auf dem Port COM31
processing.app.debug.RunnerException
	at cc.arduino.packages.uploaders.SerialUploader.uploadUsingPreferences(SerialUploader.java:152)
	at cc.arduino.UploaderUtils.upload(UploaderUtils.java:77)
	at processing.app.SketchController.upload(SketchController.java:732)
	at processing.app.SketchController.exportApplet(SketchController.java:703)
	at processing.app.Editor$UploadHandler.run(Editor.java:2071)
	at java.lang.Thread.run(Thread.java:748)
Caused by: processing.app.SerialException: Fehler beim Ansprechen des seriellen Ports "COM31".
	at processing.app.Serial.touchForCDCReset(Serial.java:107)
	at cc.arduino.packages.uploaders.SerialUploader.uploadUsingPreferences(SerialUploader.java:136)
	... 5 more
Caused by: jssc.SerialPortException: Port name - COM31; Method name - openPort(); Exception type - Port busy.
	at jssc.SerialPort.openPort(SerialPort.java:164)
	at processing.app.Serial.touchForCDCReset(Serial.java:101)
	... 6 more
```
I then have to manually kill the `avrdude.exe` process.

After that, my board isn't recognized by my PC anymore.

Trying to connect a button between RST and GND and pressing it once or twice after the USB plug is inserted also doesn't make a difference. (Or holding RST during insertion and then releasing it).

I'll try and recover my board using an external programmer, but I at least want to document that this was happening to a stock board.

MCUdude, 2021-03-20:
I've bought my Pro Micro clones from China, and I've never had any issues. Maybe the bootloader is slightly different. In the past, I've had issues with my Olimex Leonardo board that would only accept the Arduino Micro bootloader, and not the Leonardo one. Perhaps this is something that may relate to this as well? I don't know...

You can always re-flash the Pro micro bootloader again using an external programmer, so it isn't really "bricked".
What happens if you re-burn the bootloader and _just_ run the avrdude command shown in the IDE output window?

Bottom line: The reason why I don't use the Pro Micro or the Leonardo for tinkering is that the bootloader tends to be very picky sometimes. It's definitely not as reliable as an Arduino UNO (or any AVR microcontroller running the Optiboot bootloader).

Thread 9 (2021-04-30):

Have you ever got your microUPDI working on MacOS Big Sur?

tombull, 2021-04-30:
If so, how? For me, avrdude will not communicate with the microUPDI (or any other mEDBG / nEDBG devices) on Big Sur. Most often get something like `usbdev_open(): no usable interface found` or another `usbdev_open()` error, and I've not found any way to get it to work.

tombull, 2021-04-30:
(Note: this is really not an issue with microUPDI - if anything, it's an issue with MacOS Big Sur... so whatever the answer is, please feel free to close this issue!)

MCUdude, 2021-04-30:
Hi!

Nope, I haven't tried with Big Sur. I'm planning to wait as long as I can before installing it because it's known to break lots of stuff like 32-bit support. You could try to install MPLAB X and see if it provides drivers Avrdude can use. I'll also recommend you to ask over at the Avrfreaks forum. I'm sure some of the gurus over there know.

tombull, 2021-04-30:
Thanks, I've got MPLAB X installed, but avrdude still doesn't like communicating with any programmers apart from JTAG2UPDI, sadly. For reference, if anyone in the future finds this with the same issue, I posted on Avrfreaks here: [MacOS Big Sur & avrdude with mEDBG, nEDBG or ATMEL-ICE](https://www.avrfreaks.net/forum/macos-big-sur-avrdude-medbg-nedbg-or-atmel-ice).

Closed 2021-04-30.

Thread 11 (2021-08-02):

connect 4808

yourSpace24, 2021-08-02:
Hi, i was able to program the pro micro

if i use arduino to check after the upload the programmer i got following data:

BN: Arduino Uno WiFi Rev2
VID: 03eb
PID: 2145
SN: MICROUPDIPROGRAMMERX

then i hook it up to a 4808 atmel and try to upload the firmware via arduino and get following error:

Global variables use 527 bytes (8%) of dynamic memory, leaving 5617 bytes for local variables. Maximum is 6144 bytes.
avrdude: usbdev_open(): WARNING: failed to set configuration 1: Device or resource busy
avrdude: bad response to AVR sign-on command: 0xa0
avrdude: retrying with external reset applied
avrdude: bad response to AVR sign-on command: 0xa0
avrdude: retrying with external reset applied
avrdude: JTAGEN fuse disabled?
avrdude: initialization failed, rc=-1
         Double check connections and try again, or use -F to override
         this check.

An error occurred while uploading the sketch

the programmer is connected via ground and updi to the atmel 4808 chip it is a brand new one. I checked with an oscilloscope the updi pin to see what it is going on. An some bits are showing up.

could it be that it is a permission problem on the linux machine or is there a way to check a kind of simple communication to verify that everything is okay. The atmega 4808 runs on 3.3 volt.

many thanks

cheers

yourSpace24, 2021-08-02:
avrdude -v -patmega4808 -cxplainedmini_updi -Pusb -b115200 -e

avrdude: Version 6.3-20171130
         Copyright (c) 2000-2005 Brian Dean, http://www.bdmicro.com/
         Copyright (c) 2007-2014 Joerg Wunsch

         System wide configuration file is "/etc/avrdude.conf"
         User configuration file is "/root/.avrduderc"
         User configuration file does not exist or is not a regular file, skipping

         Using Port                    : usb
   Using Programmer              : xplainedmini_updi
         Overriding Baud Rate          : 115200
avrdude: Found CMSIS-DAP compliant device, using EDBG protocol
         AVR Part                      : ATmega4808
         Chip Erase delay              : 0 us
         PAGEL                         : P00
         BS2                           : P00
         RESET disposition             : dedicated
         RETRY pulse                   : SCK
         serial program mode           : yes
         parallel program mode         : yes
         Timeout                       : 0
         StabDelay                     : 0
         CmdexeDelay                   : 0
         SyncLoops                     : 0
         ByteDelay                     : 0
         PollIndex                     : 0
         PollValue                     : 0x00
         Memory Detail                 :

                                  Block Poll               Page                       Polled
           Memory Type Mode Delay Size  Indx Paged  Size   Size #Pages MinW  MaxW   ReadBack
           ----------- ---- ----- ----- ---- ------ ------ ---- ------ ----- ----- ---------
           signature      0     0     0    0 no          3    0      0     0     0 0x00 0x00
           prodsig        0     0     0    0 no         61   61      0     0     0 0x00 0x00
           fuses          0     0     0    0 no          9    0      0     0     0 0x00 0x00
           fuse0          0     0     0    0 no          1    0      0     0     0 0x00 0x00
           fuse1          0     0     0    0 no          1    0      0     0     0 0x00 0x00
           fuse2          0     0     0    0 no          1    0      0     0     0 0x00 0x00
           fuse4          0     0     0    0 no          1    0      0     0     0 0x00 0x00
           fuse5          0     0     0    0 no          1    0      0     0     0 0x00 0x00
           fuse6          0     0     0    0 no          1    0      0     0     0 0x00 0x00
           fuse7          0     0     0    0 no          1    0      0     0     0 0x00 0x00
           fuse8          0     0     0    0 no          1    0      0     0     0 0x00 0x00
           lock           0     0     0    0 no          1    0      0     0     0 0x00 0x00
           data           0     0     0    0 no          0    0      0     0     0 0x00 0x00
           usersig        0     0     0    0 no         64   64      0     0     0 0x00 0x00
           flash          0     0     0    0 no      49152  128      0     0     0 0x00 0x00
           eeprom         0     0     0    0 no        256   64      0     0     0 0x00 0x00

         Programmer Type : JTAGICE3_UPDI
         Description     : Atmel AVR XplainedMini in UPDI mode
         ICE hardware version: 0
         ICE firmware version: 1.19 (rel. 57)
         Serial number   : MICROUPDIPROGRAMMERX
         Vtarget         : 5.00 V
         JTAG clock megaAVR/program: 0 kHz
         JTAG clock megaAVR/debug:   0 kHz
         JTAG clock Xmega: 0 kHz
         PDI clock Xmega : 0 kHz

avrdude: Short read, read only 0 out of 64 bytes
avrdude: jtag3_edbg_recv(): Unexpected response 0xf0
avrdude: retrying with external reset applied
avrdude: Failed to write 64 bytes to USB
avrdude: jtag3_edbg_send(): failed to send command to serial port
avrdude: bad response to AVR sign-on command: 0xa0
avrdude: retrying with external reset applied
avrdude: JTAGEN fuse disabled?
avrdude: initialization failed, rc=-1
         Double check connections and try again, or use -F to override
         this check.

avrdude: jtag3_edbg_send(): Unexpected response 0x81, 0x00
avrdude: jtag3_edbg_recv(): Unexpected response 0x80
avrdude: jtag3_edbg_send(): Unexpected response 0x81, 0x11
avrdude: jtag3_edbg_recv(): Unexpected response 0x80
avrdude: jtag3_edbg_signoff(): unexpected response 0x81, 0x11
avrdude: jtag3_edbg_signoff(): unexpected response 0x01, 0x00

avrdude done.  Thank you.

MCUdude, 2021-08-02:
Are you using a microUPDI programmer, or is is a breadboarded pro micro? What resistor value do you use in series on the UPDI line? Are you able to run the 4808 on 5V, just to check?

yourSpace24, 2021-08-02:
i use the pro micro with the micro updi firmware

yourSpace24, 2021-08-02:
with the 330Ohm resistor on the updi pin

yourSpace24, 2021-08-02:
the 4808 runs on its own LDO 3.3 volt i connect only the GND and updi to the programmer runs on 5v

yourSpace24, 2021-08-02:
Here the full avrdude comand i always get different device signatures
<pre>
root@HAL9000:~# /home/theurlm/.arduino15/packages/arduino/tools/avrdude/6.3.0-arduino18/bin/avrdude -C /home/theurlm/.arduino15/packages/MegaCoreX/hardware/megaavr/1.0.8/avrdude.conf -v -patmega4808 -cxplainedmini_updi -Pusb -Uflash:w:/home/theurlm/Arduino/PV.MUX.200_REV.A/PV.MUX.200_REV.A.ino_atmega4808_16000000L.hex:i  -b8 -F

avrdude: Version 6.3-20201216
         Copyright (c) 2000-2005 Brian Dean, http://www.bdmicro.com/
         Copyright (c) 2007-2014 Joerg Wunsch

         System wide configuration file is "/home/theurlm/.arduino15/packages/MegaCoreX/hardware/megaavr/1.0.8/avrdude.conf"
         User configuration file is "/root/.avrduderc"
         User configuration file does not exist or is not a regular file, skipping

         Using Port                    : usb
         Using Programmer              : xplainedmini_updi
         Overriding Baud Rate          : 8
avrdude: usbdev_open(): Found mEDBG CMSIS-DAP, serno: MICROUPDIPROGRAMMERX
avrdude: usbdev_open(): WARNING: failed to set configuration 1: Device or resource busy
avrdude: max packet size expected 912, but found 64 due to EP 0x81's wMaxPacketSize
avrdude: Found CMSIS-DAP compliant device, using EDBG protocol
         AVR Part                      : ATmega4808
         Chip Erase delay              : 0 us
         PAGEL                         : P00
         BS2                           : P00
         RESET disposition             : dedicated
         RETRY pulse                   : SCK
         serial program mode           : yes
         parallel program mode         : yes
         Timeout                       : 0
         StabDelay                     : 0
         CmdexeDelay                   : 0
         SyncLoops                     : 0
         ByteDelay                     : 0
         PollIndex                     : 0
         PollValue                     : 0x00
         Memory Detail                 :

                                  Block Poll               Page                       Polled
           Memory Type Mode Delay Size  Indx Paged  Size   Size #Pages MinW  MaxW   ReadBack
           ----------- ---- ----- ----- ---- ------ ------ ---- ------ ----- ----- ---------
           signature      0     0     0    0 no          3    0      0     0     0 0x00 0x00
           prodsig        0     0     0    0 no         61   61      0     0     0 0x00 0x00
           fuses          0     0     0    0 no          9    0      0     0     0 0x00 0x00
           fuse0          0     0     0    0 no          1    0      0     0     0 0x00 0x00
           fuse1          0     0     0    0 no          1    0      0     0     0 0x00 0x00
           fuse2          0     0     0    0 no          1    0      0     0     0 0x00 0x00
           fuse4          0     0     0    0 no          1    0      0     0     0 0x00 0x00
           fuse5          0     0     0    0 no          1    0      0     0     0 0x00 0x00
           fuse6          0     0     0    0 no          1    0      0     0     0 0x00 0x00
           fuse7          0     0     0    0 no          1    0      0     0     0 0x00 0x00
           fuse8          0     0     0    0 no          1    0      0     0     0 0x00 0x00
           lock           0     0     0    0 no          1    0      0     0     0 0x00 0x00
           data           0     0     0    0 no          0    0      0     0     0 0x00 0x00
           usersig        0     0     0    0 no         64   64      0     0     0 0x00 0x00
           flash          0     0     0    0 no      49152  128      0     0     0 0x00 0x00
           eeprom         0     0     0    0 no        256   64      0     0     0 0x00 0x00

         Programmer Type : JTAGICE3_UPDI
         Description     : Atmel AVR XplainedMini in UPDI mode
         ICE hardware version: 0
         ICE firmware version: 1.19 (rel. 57)
         Serial number   : MICROUPDIPROGRAMMERX
         Vtarget         : 5.00 V
         JTAG clock megaAVR/program: 0 kHz
         JTAG clock megaAVR/debug:   0 kHz
         JTAG clock Xmega: 0 kHz
         PDI clock Xmega : 0 kHz
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
MCUdude, 2021-08-02:
Can you try to connect the AVCC pin to 5V on the Pro Micro?

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

The reason for this is that the original mEDBG firmware requires to do this in hardware. However, the microUPDI hex file has been modified, so AVCC should now be connected to VCC internally. But you should still try this mod to check if it makes a difference.

yourSpace24, 2021-08-03:
hi, same result i tried as well with the atmega 4808 on 5volt same result something is not working. Is there a way to check if the programmer is working correct ?

yourSpace24, 2021-08-03:
Hi again, ok made a new PCB added a new atmega 4808 on and now it is working (5v). Maybe the other one got fried. Just to be sure is the 3.3 volt target system okay ? or could be this a issue. many thanks

MCUdude, 2021-08-03:
Well, I have a test board for the ATmegaXX08 chips where I can set the target voltage to 3.3V. I'm able to upload to it just fine using a microUPDI programmer. So I don't think a 3.3V system should be an issue. You could try to change the series resistor to something higher, for instance, 470R or 1k

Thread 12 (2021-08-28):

Debug and serial monitor

paulskirk53, 2021-08-28:
If I use my microUPDI as a debug tool in MCSudio, it works fine. However, as part of the debug session, I'd like to send and receive chars over USART on my AVR4809. Currently I'm trying to do the serial comms using the Arduino sermon, but the problem I have is when debug is active in MCStudio, the Arduino Sermon is inactive. If I stop the debug session in MCStudio, the Arduino Sermon becomes active again. So my question is - Is it possible to run the debug session and serial data transmit/ receive simultaneously?
thanks.

MCUdude, 2021-08-28:
I haven't really tried to use it as a debugger while also having an active Serial monitor. Does the COM port disappear from the Windows device manager when you start a debug session? If so, I don't think you can do both at the same time.

paulskirk53, 2021-08-28:
Interesting, it does work, the COM port is available during debug. I have a live debug session in Microchip studio and a live Serial Monitor in arduino IDE.
What doesn't seem to work (and what prompted my original post), is if I set a breakpoint with an action to log a message and variable value in the output window and check the 'continue execution box'. In that configuration, the serial monitor is inactive.

I don't think its a problem with the microUPDI

thanks for reply.

MCUdude, 2021-08-28:
Thanks for the explanation! You could try a different terminal program, such as Realterm to figure out if it is the programmer's fault or not

paulskirk53, 2021-08-28:
I tried it with X-CTU as well, and it's possible to debug in MCStudio and simultaneously send and receive chars over X-CTU. Nice.

thanks.

MCUdude, 2021-08-28:
Great to hear you figured it out!

Closed 2021-08-28.

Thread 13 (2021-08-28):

Printable case for the microUPDI

egeltje, 2021-08-28:
I have just uploaded a printable case for the microUPDI to thingiverse. I find it useful and perhaps others might find it useful too.
https://www.thingiverse.com/thing:4943607

MCUdude, 2021-08-28:
Thanks for sharing, that is a quite nice case indeed!

To my surprise, the microUPDI has turned out to be the most popular board I sell on Tindie, even though there are many good UPDI programmer alternatives out there.
Few people also leave feedback, so I feel like I should ask; What made you buy the microUPDI and not all the other alternatives out there like the JTAG2UPDI, Microchip SNAP, PICkit4? Was it the price point, functionality, or software support? 🙂
Anyways, I hope you're happy with yours!

egeltje, 2021-08-30:
I have created one (http://fabacademy.org/2021/labs/waag/students/kooi-erwin/report/week_04/#project-updi) of the 4k7 resistor ones (with a ft2301 serial converter) and pyupdi tool but that gave sometimes finicky results. As I have fallen in love with the new iteration of the AVR family, it was time for a more solid programmer.
And to somewhat support your work on the Arduino code for supporting these uC's. :-)

merlinblack, 2022-01-13:
> And to somewhat support your work on the Arduino code for supporting these uC's. :-)
That's also why I bought one of your boards too :-) And your Mighty, Micro, Mega, etc cores too.

platima, 2024-11-13:
> I have just uploaded a printable case for the microUPDI to thingiverse. I find it useful and perhaps others might find it useful too. https://www.thingiverse.com/thing:4943607

Nice one! Do you mind if I 3D print these en-mass and list them in my store to buy? I'd just be charging for the time & material, not your design, and of course link to your files!

If not, all good too! Just trying to stock more cases these days, as there are not enough!

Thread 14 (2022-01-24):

Custom UPDI programmer and ATmega4809

ITstreet1, 2022-01-24:
I tried to build a stand-alone programmer and a simple board with 4809 but something I didn't do good enough.

UPDI programmer
This programmer I made according to the schematic of an add-on board and the schematic of the Sparkfun Pro Micro 5V.
This programmer is alive and while following the steps here, I flash it, and it goes fine. My PC recognizes it as mEDBG Virtual Port. This part should be ok.

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

As you can see, there is not much. Only what needs to be.

ATmega4809 board
I followed the barebone schematic here as well. Just solder all the necessary things, but when trying to upload a basic Blink sketch I get errors.

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

On this second board, I didn't solder the 3.3V regulator, LEDs, etc. Only the basic.

I choose MegaCoreX, Atmega4809
Internal clock 16MHz
BOD 2.6V
48 pin standard
Reset pin: Reset
No Bootloader
Programmer mEDBG/microUPDI

To upload I use Sketch->Upload using programmer

How to troubleshoot this? From where to start?
Are my wirings ok?
Did I choose the right options in Arduino IDE?
Do I need a step or two before uploading the sketch?

Thank you in advance.

MCUdude, 2022-01-24:
Are you able to program your ATmega4809 board with a different UPDI programmer, for instance, a JTAG2UPDI? And which error are you getting from Avrdude?

ITstreet1, 2022-01-24:
I just saw I didn't connect PF0 and PF1 to the UPDI connector as an RX and TX

MCUdude, 2022-01-24:
> I just saw I didn't connect PF0 and PF1 to the UPDI connector as an RX and TX

Did this solve your issue?

ITstreet1, 2022-01-24:
This is what I get:

```
avrdude: Short read, read only 0 out of 64 bytes
avrdude: jtag3_edbg_recv(): Unexpected response 0x90
avrdude: retrying with external reset applied
avrdude: jtag3_edbg_send(): Unexpected response 0x81, 0x11
avrdude: jtag3_edbg_recv(): Unexpected response 0x80
avrdude: retrying with external reset applied
avrdude: JTAGEN fuse disabled?
avrdude: initialization failed, rc=-1
         Double check connections and try again, or use -F to override
         this check.

avrdude: jtag3_edbg_send(): Unexpected response 0x81, 0x11
avrdude: jtag3_edbg_recv(): Unexpected response 0x80
avrdude: jtag3_edbg_send(): Unexpected response 0x81, 0x11
avrdude: jtag3_edbg_recv(): Unexpected response 0x80
avrdude: jtag3_edbg_signoff(): unexpected response 0x81, 0x11
An error occurred while uploading the sketch
avrdude: jtag3_edbg_signoff(): unexpected response 0x01, 0x00
```

ITstreet1, 2022-01-24:
I cut the wrong RX/TX traces and rewire them. Error as above.

I have no idea what this means, except I have to check my connections.
Connections are good. Now. :)
I could mess a thing or two with programmer, 4809 board or both

MCUdude, 2022-01-24:
I have sold _many_ microUPDI boards, and as far as I know, none of the buyers has had any issues getting it to work.

The problem with your setup is that you have two potential sources of error, the programmer and the board. Get yourself a programmer you _know_ works, for instance, a DIY JTAG2UPDI programmer using an ATmega328 based board such as an Arduino UNO or Nano.

ITstreet1, 2022-01-24:
OK.
As far as I can see, it uses the UPDI line only.
Another thing, I have to disable the reset. The easiest way is to use a Pro Mini, 5V. I can disconnect the DTR pin.
Anything else I should have to do?

merlinblack, 2022-02-21:
With my microUPDI I'm seeing the same problem with avrdude compiled from source, but not with the avrdude included with the Arduino IDE (1.8) on Fedora. Works really well with Atmel Studio 7 in windows too.

I want to get avrdude from source as the Arduino IDE one is kinda weird in other ways, and also I want to compile for a raspberry pi.

It's quite possibly my less-than-great soldering, but it's weird it always works for some ways, but not others.

Possibly related is that I get gibberish serial comms as if the baud is wrong via the microUPDI, but the serial from 4809 works via another serial to USB I have (set at 115200).

```
avrdude: Version 6.99-20220211 (7b79b72)
         Copyright (c) Brian Dean, http://www.bdmicro.com/
         Copyright (c) Joerg Wunsch

         System wide configuration file is "/home/nigel/prog/avr/avrdude/build_linux/src/avrdude.conf"
         User configuration file is "/home/nigel/.avrduderc"
         User configuration file does not exist or is not a regular file, skipping

         Using Port                    : usb
         Using Programmer              : xplainedmini_updi
avrdude: Found CMSIS-DAP compliant device, using EDBG protocol
         AVR Part                      : ATmega4809
         RESET disposition             : dedicated
         RETRY pulse                   : SCK
         Serial program mode           : yes
         Parallel program mode         : yes
         Memory Detail                 :

                                           Block Poll               Page                       Polled
           Memory Type Alias    Mode Delay Size  Indx Paged  Size   Size #Pages MinW  MaxW   ReadBack
           ----------- -------- ---- ----- ----- ---- ------ ------ ---- ------ ----- ----- ---------
           signature               0     0     0    0 no          3    1      0     0     0 0x00 0x00
           prodsig                 0     0     0    0 no         61   61      0     0     0 0x00 0x00
           sernum                  0     0     0    0 no         10    1      0     0     0 0x00 0x00
           osccal16                0     0     0    0 no          2    1      0     0     0 0x00 0x00
           osccal20                0     0     0    0 no          2    1      0     0     0 0x00 0x00
           tempsense               0     0     0    0 no          2    1      0     0     0 0x00 0x00
           osc16err                0     0     0    0 no          2    1      0     0     0 0x00 0x00
           osc20err                0     0     0    0 no          2    1      0     0     0 0x00 0x00
           fuses                   0     0     0    0 no          9   10      0     0     0 0x00 0x00
           fuse0       wdtcfg      0     0     0    0 no          1    1      0     0     0 0x00 0x00
           fuse1       bodcfg      0     0     0    0 no          1    1      0     0     0 0x00 0x00
           fuse2       osccfg      0     0     0    0 no          1    1      0     0     0 0x00 0x00
           fuse4       tcd0cfg     0     0     0    0 no          1    1      0     0     0 0x00 0x00
           fuse5       syscfg0     0     0     0    0 no          1    1      0     0     0 0x00 0x00
           fuse6       syscfg1     0     0     0    0 no          1    1      0     0     0 0x00 0x00
           fuse7       append      0     0     0    0 no          1    1      0     0     0 0x00 0x00
           fuse8       bootend     0     0     0    0 no          1    1      0     0     0 0x00 0x00
           lock                    0     0     0    0 no          1    1      0     0     0 0x00 0x00
           data                    0     0     0    0 no          0    1      0     0     0 0x00 0x00
           usersig                 0     0     0    0 no         64   64      0     0     0 0x00 0x00
           flash                   0     0     0    0 no      49152  128      0     0     0 0x00 0x00
           eeprom                  0     0     0    0 no        256   64      0     0     0 0x00 0x00

         Programmer Type : JTAGICE3_UPDI
         Description     : Atmel AVR XplainedMini in UPDI mode
         ICE HW version  : 0
         ICE FW version  : 1.19 (rel. 57)
         Serial number   : MICROUPDIPROGRAMMERX
         Vtarget         : 3.30 V
avrdude: Short read, read only 0 out of 64 bytes
avrdude: jtag3_edbg_recv(): Unexpected response 0x58
avrdude: retrying with external reset applied
avrdude: jtag3_edbg_send(): Unexpected response 0x81, 0x11
avrdude: jtag3_edbg_recv(): Unexpected response 0x80
avrdude: retrying with external reset applied
avrdude: JTAGEN fuse disabled?
avrdude: initialization failed, rc=-1
         Double check connections and try again, or use -F to override
         this check.

avrdude: jtag3_edbg_send(): Unexpected response 0x81, 0x11
avrdude: jtag3_edbg_recv(): Unexpected response 0x80
avrdude: jtag3_edbg_send(): Unexpected response 0x81, 0x11
avrdude: jtag3_edbg_recv(): Unexpected response 0x80

avrdude done.  Thank you.
```

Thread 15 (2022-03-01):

Arduino IDE won't flash Pro Micro

lmorris99, 2022-03-01:
Using Arduino 1.8.16:
Installed microUPDI flash tool without issue;
selected it;
connected ProMicro to my Mac (Big Sur, 11.6.2 if that's relevant)
Click Upload button: got this:

```
avrdude: Version 6.3-20190619
         Copyright (c) 2000-2005 Brian Dean, http://www.bdmicro.com/
         Copyright (c) 2007-2014 Joerg Wunsch

         System wide configuration file is "/Users/lindsay/Library/Arduino15/packages/arduino/tools/avrdude/6.3.0-arduino17/etc/avrdude.conf"
         User configuration file is "/Users/lindsay/.avrduderc"
         User configuration file does not exist or is not a regular file, skipping

         Using Port                    : /dev/cu.usbmodem1464201
         Using Programmer              : avr109
         Overriding Baud Rate          : 57600
         AVR Part                      : ATmega32U4
         Chip Erase delay              : 9000 us
         PAGEL                         : PD7
         BS2                           : PA0
         RESET disposition             : dedicated
         RETRY pulse                   : SCK
         serial program mode           : yes
         parallel program mode         : yes
         Timeout                       : 200
         StabDelay                     : 100
         CmdexeDelay                   : 25
         SyncLoops                     : 32
         ByteDelay                     : 0
         PollIndex                     : 3
         PollValue                     : 0x53
         Memory Detail                 :

                                  Block Poll               Page                       Polled
           Memory Type Mode Delay Size  Indx Paged  Size   Size #Pages MinW  MaxW   ReadBack
           ----------- ---- ----- ----- ---- ------ ------ ---- ------ ----- ----- ---------
           eeprom        65    20     4    0 no       1024    4      0  9000  9000 0x00 0x00
           flash         65     6   128    0 yes     32768  128    256  4500  4500 0x00 0x00
           lfuse          0     0     0    0 no          1    0      0  9000  9000 0x00 0x00
           hfuse          0     0     0    0 no          1    0      0  9000  9000 0x00 0x00
           efuse          0     0     0    0 no          1    0      0  9000  9000 0x00 0x00
           lock           0     0     0    0 no          1    0      0  9000  9000 0x00 0x00
           calibration    0     0     0    0 no          1    0      0     0     0 0x00 0x00
           signature      0     0     0    0 no          3    0      0     0     0 0x00 0x00

         Programmer Type : butterfly
         Description     : Atmel AppNote AVR109 Boot Loader

Connecting to programmer: .
Found programmer: Id = "j>���"; type = *
    Software Version = *.�; Hardware Version =  .�
avrdude: error: buffered memory access not supported. Maybe it isn't
a butterfly/AVR109 but a AVR910 device?
avrdude: initialization failed, rc=-1
         Double check connections and try again, or use -F to override
         this check.

avrdude: error: programmer did not respond to command: leave prog mode
avrdude: error: programmer did not respond to command: exit bootloader

avrdude done.  Thank you.
```
Perhap[s it worked in spite of the error messages? Installation instructions say  "in Arduino IDE it will show up as an *Arduino UNO WiFi Rev2."  I'm not sure where in Arduino that's supposed to show up: as a Port? as a Board? I do find an Arduino UNO WiFi Rev2 board under "Arduino MegaAVR boards", but that entry is there whether I plug in to pro Micro or not.

So --- I'm trying to follow instructions - something's gone wrong for me.  Advice appreciated.  Thanks!

lmorris99, 2022-03-03:
probably had a bad USB cable. Working now.

Closed 2022-03-03.

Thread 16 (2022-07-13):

Question : Can I use 3.3V Pro Micro

hallard, 2022-07-13:
If I need to program only 3.3V target, can I use 3.3V Pro micro (I have only this version in hand) or does the firmware going into the pro-micro (8MHz) will not work due to different speed?
I'm pretty sure it will not work until FW is build for 8MHz but worth asking

platima, 2024-11-13:
It would likely work in some scenarios, as UPDI should be fairly tolerant of speed changes and I think operates at way less than 8MHz (0.25-1MHz I think), but may have bugs.

You'd need to change
`microupdi.build.f_cpu=16000000L`
In boards.txt

I don't have Altium though, so I am unsure if microUPDI circuitry taps off RAW, which would still allow you to use 5V targets, else if it uses VCC, you'll be limited to 3.3V targets.

@MCUdude can probably confirm this!

Else, just try it and find out 😊 I don't see it harming anything.

MCUdude, 2024-11-14:
The original EDBG programmers all ran at 16 MHZ and 5V. But feel free to try it. I'm not actually sure if the AVR uses the CLKPR register to clock the 16 MHZ clock down to 8 internally.

Closed 2024-11-17.

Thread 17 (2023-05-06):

Firmware upload fails

paulskirk53, 2023-05-06:
Hi, I'm using the arduino IDE 1.8.13 and can't get the firmware to upload.
My arduino pro micro has a reset pin and I tried grounding that as the upload started, but it has no effect. Anything else I can try please?

error msg from IDE:

Arduino: 1.8.13 (Windows 10), Board: "microUPDI Firmware Uploader"

Sketch uses 0 bytes (0%) of program storage space. Maximum is 28672 bytes.

Global variables use 0 bytes (0%) of dynamic memory, leaving 2560 bytes for local variables. Maximum is 2560 bytes.

Couldn't find a Board on the selected port. Check that you have the correct port selected.  If it is correct, try pressing the board's reset button after initiating the upload.

This report would have more information with
"Show verbose output during compilation"
option enabled in File -> Preferences.

paulskirk53, 2023-05-07:
I tried using a Uno as ISP with SPI and gnd pins connected to the pro micro, with both devices powered, in order to burn a bootoader for the pro micro. It didn't work, so I also used avrdude from a windows command line with -F as below, but no success, just get 'invalid device signature' when burning the bootloader. Any thoughts much appreciated.

C:\Users\Paul\AppData\Local\Arduino15\packages\arduino\tools\avrdude\6.3.0-arduino17/bin/avrdude -CC:\Users\Paul\AppData\Local\Arduino15\packages\arduino\tools\avrdude\6.3.0-arduino17/etc/avrdude.conf -v -F -patmega32u4 -cstk500v1 -PCOM24 -b19200 -e -Ulock:w:0x3F:m -Uefuse:w:0xCB:m -Uhfuse:w:0xD8:m -Ulfuse:w:0xFF:m

paulskirk53, 2023-05-07:
ok so I got the sparkfun bootlaoder loaded (I missed out pin 10 of the arduino programmer which resets the pro micro), but the pro micro does not present a COM port in the arduino IDE. So I have tried :
-reset twice within 0.75 seconds to set the bootloader timeout to 8 seconds
-reset as I upload a sketch
but no port becomes available.
thanks for help with this.

paulskirk53, 2023-05-07:
looks like it was a faulty USB cable...:( I now have a port assigned to the pro micro using the reset immediately before upload technique.

paulskirk53, 2023-05-07:
ok, now finally got mEDBG virtual com port in windows device manager. The board has to be reset manually (two wires and a pushbutton switch temporarily installed onto pro micro rst and gnd) before upload even when the pro micro port is selected.
It's worth knowing that the standard sparkfun bootloader timeout is 750mS, which can be changed to 8 seconds by resetting the board twice within the 750 mS. It makes it much easier later on when the pro micro has to be reset when uploading the firmware. Good luck :)

paulskirk53, 2023-05-08:
Ok so I made good progress, but the code upload just hangs. Using Arduino ide, the tools menu has these items in it when the microUPDI is connected:
Board ATMega4809
clock internal 16Mhz
BOd 2.6V
Pinout "40 pin standard"
reset pin "Reset"
Bootloader no bootloader
Port "COM10 (Arduino Uno wifi Rev 2)"
get board info
Programmer "Atmel mEDBG (ATmega32U4)"
Burn bootloader

The IDE just contains empty setup() and Loop() functions

When I click the upload icon in the ide, the message window shows the following and the process just hangs indefinitely.

Any help much appreciated

Sketch uses 510 bytes (1%) of program storage space. Maximum is 49152 bytes.
Global variables use 4 bytes (0%) of dynamic memory, leaving 6140 bytes for local variables. Maximum is 6144 bytes.
C:\Users\Paul\AppData\Local\Arduino15\packages\arduino\tools\avrdude\6.3.0-arduino18/bin/avrdude -CC:\Users\Paul\AppData\Local\Arduino15\packages\MegaCoreX\hardware\megaavr\1.0.7/avrdude.conf -v -patmega4809 -cxplainedmini_updi -Pusb -Uflash:w:C:\Users\Paul\AppData\Local\Temp\arduino_build_12643/sketch_may08a.ino.with_bootloader.hex:i -Ufuse0:w:0x00:m -Ufuse1:w:0x54:m -Ufuse2:w:0x01:m -Ufuse4:w:0x00:m -Ufuse5:w:0xC9:m -Ufuse6:w:0x06:m -Ufuse7:w:0x00:m -Ufuse8:w:0x00:m -Ulock:w:0xC5:m

avrdude: Version 6.3-20201216
         Copyright (c) 2000-2005 Brian Dean, http://www.bdmicro.com/
         Copyright (c) 2007-2014 Joerg Wunsch

         System wide configuration file is "C:\Users\Paul\AppData\Local\Arduino15\packages\MegaCoreX\hardware\megaavr\1.0.7/avrdude.conf"

         Using Port                    : usb
         Using Programmer              : xplainedmini_updi

when I unplug the USB cable, the message window shows:

avrdude: usbhid_open(): No response from device
avrdude: jtag3_open_common(): Did not find any device matching VID 0x03eb and PID list: 0x2145

avrdude done.  Thank you.

An error occurred while uploading the sketch

MCUdude, 2023-05-08:
Hi Paul!

> megaavr\1.0.7

Please download the latest MegaCoreX version. Avrdude 6.3 has been replaced with Avrdude 7.1, which should work much better with the microUPDI

paulskirk53, 2023-05-09:
Hi, I have installed avrdude 7.1 and its .conf file

I tried to reinsall the firmware, but I now get the output below from Arduino IDE, any help much appreciated.

Arduino: 1.8.13 (Windows 10), Board: "microUPDI Firmware Uploader"

Sketch uses 0 bytes (0%) of program storage space. Maximum is 28672 bytes.

Global variables use 0 bytes (0%) of dynamic memory, leaving 2560 bytes for local variables. Maximum is 2560 bytes.

Forcing reset using 1200bps open/close on port COM10

PORTS {COM1, COM10, } / {COM1, COM10, } => {}

PORTS {COM1, COM10, } / {COM1, COM10, } => {}

PORTS {COM1, COM10, } / {COM1, COM10, } => {}

PORTS {COM1, COM10, } / {COM1, COM10, } => {}

PORTS {COM1, COM10, } / {COM1, } => {}

PORTS {COM1, } / {COM1, } => {}

PORTS {COM1, } / {COM1, } => {}

PORTS {COM1, } / {COM1, } => {}

PORTS {COM1, } / {COM1, } => {}

PORTS {COM1, } / {COM1, COM10, } => {COM10, }

Found upload port: COM10

C:\Users\Paul\AppData\Local\Arduino15\packages\microUPDIcore\hardware\avr\1.0.2/scripts/avrdude-wrapper.bat C:\Users\Paul\AppData\Local\Arduino15\packages\arduino\tools\avrdude\6.3.0-arduino17/bin/avrdude C:\Users\Paul\AppData\Local\Arduino15\packages\arduino\tools\avrdude\6.3.0-arduino17/etc/avrdude.conf atmega32u4 avr109 COM10 57600 C:\Users\Paul\AppData\Local\Arduino15\packages\microUPDIcore\hardware\avr\1.0.2 C:\Users\Paul\AppData\Local\Temp\arduino_build_456569

avrdude: Version 7.1

         Copyright the AVRDUDE authors;

         see https://github.com/avrdudes/avrdude/blob/main/AUTHORS

         System wide configuration file is C:\Users\Paul\AppData\Local\Arduino15\packages\arduino\tools\avrdude\6.3.0-arduino17\etc\avrdude.conf

         Using Port                    : COM10

         Using Programmer              : avr109

         Overriding Baud Rate          : 57600

         AVR Part                      : ATmega32U4

         Chip Erase delay              : 9000 us

         PAGEL                         : PD7

         BS2                           : PA0

         RESET disposition             : possible i/o

         RETRY pulse                   : SCK

         Serial program mode           : yes

         Parallel program mode         : yes

         Timeout                       : 200

         StabDelay                     : 100

         CmdexeDelay                   : 25

         SyncLoops                     : 32

         PollIndex                     : 3

         PollValue                     : 0x53

         Memory Detail                 :

                                           Block Poll               Page                       Polled

           Memory Type Alias    Mode Delay Size  Indx Paged  Size   Size #Pages MinW  MaxW   ReadBack

           ----------- -------- ---- ----- ----- ---- ------ ------ ---- ------ ----- ----- ---------

           eeprom                 65    20     4    0 no       1024    4      0  9000  9000 0x00 0x00

           flash                  65     6   128    0 yes     32768  128    256  4500  4500 0x00 0x00

           lfuse                   0     0     0    0 no          1    1      0  9000  9000 0x00 0x00

           hfuse                   0     0     0    0 no          1    1      0  9000  9000 0x00 0x00

           efuse                   0     0     0    0 no          1    1      0  9000  9000 0x00 0x00

           lock                    0     0     0    0 no          1    1      0  9000  9000 0x00 0x00

           signature               0     0     0    0 no          3    1      0     0     0 0x00 0x00

           calibration             0     0     0    0 no          1    1      0     0     0 0x00 0x00

         Programmer Type : butterfly

         Description     : Atmel for bootloader using AppNote AVR109

connecting to programmer: .avrdude butterfly_recv() error: programmer is not responding

avrdude butterfly_recv() error: programmer is not responding

avrdude butterfly_recv() error: programmer is not responding

avrdude butterfly_recv() error: programmer is not responding

avrdude butterfly_recv() error: programmer is not responding

avrdude butterfly_recv() error: programmer is not responding

Programmer id    = 0���� ; type = $

Software version =

paulskirk53, 2023-05-09:
In windows device manager the baord presents itself as expected:

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

but when I look in the tools > programmer menu, the only atmel option is Atmel ICE. The Atmel mEDBG (microUPDI) does not appear.

Not much hair left now :) :)

Would it be useful perhaps to erase the Pro Micro and start again from scratch?
thanks for any thoughts.

MCUdude, 2023-05-10:
Why would you want to reinstall the firmware?

The firmware that's currently on the AVR is not designed to play nicely with the built-in bootloader, so I've not been able to flash it one more time using the bootloader.

You can flash the firmware directly using Avrdude. Here's the command if you're using an Atmel ICE. I think this command should work. If not, manke sure the path to avrdude.exe, avrdude.conf and mEDBG_UPDI_1.13_no_bootloader.hex is correct.

```
C:\Users\Paul\AppData\Local\Arduino15\packages\arduino\tools\avrdude\6.3.0-arduino17/bin/avrdude.exe -C "C:\Users\Paul\AppData\Local\Arduino15\packages\arduino\tools\avrdude\6.3.0-arduino17\etc\avrdude.conf -catmelice_isp -patmega32u4 -Uflash:w:"C:\Users\Paul\AppData\Local\Arduino15\packages\microUPDIcore\hardware\avr\1.0.2/firmwares/mEDBG_UPDI_1.13_no_bootloader.hex":i
```

paulskirk53, 2023-05-10:
HI thanks for reply. I don't have an Atmel ICE. I have been through process as described for flashing the mEDBG firmware to the Pro Micro, but as I've posted, when I try to program my AVR4809 chip, the  Atmel mEDBG (microUPDI) does not appear in the IDE's programmer menu.

So where to go from here ? Any ideas much appreciated.

paulskirk53, 2023-05-10:
Also tried the programmer in Microchip studio and although it appears in the device programming tool dropdown, and is selectable, when 'Apply' is selected a 'failed to connect' error appears.

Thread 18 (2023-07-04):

Onboard Atmel mEDBG option not present in programmers menu, 'initialization' fails during upload

Sk8rSeth, 2023-07-04:
i cant seem to upload anything to my attiny1616 through the microUPDI. i am new to UPDI programming so im not sure what im doing wrong.

my pro micro was programmed with the microUPDI firmware uploader correctly, and it now shows as 'Arduino Uno WiFi Rev2' under the com port menu.
however there is no option for the 'Onboard Atmel mEDBG' under the programmers menu (see below)
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

when i try to upload a blinky sketch via Upload Using Programmer, this is the output i get:

```
avrdude: Version 6.3-20201216
         Copyright (c) 2000-2005 Brian Dean, http://www.bdmicro.com/
         Copyright (c) 2007-2014 Joerg Wunsch

         System wide configuration file is "C:\Users\Mjolnir\AppData\Local\Arduino15\packages\megaTinyCore\hardware\megaavr\2.6.8/avrdude.conf"

         Using Port                    : usb
         Using Programmer              : xplainedmini_updi
avrdude: Found CMSIS-DAP compliant device, using EDBG protocol
         AVR Part                      : ATtiny1616
         Chip Erase delay              : 0 us
         PAGEL                         : P00
         BS2                           : P00
         RESET disposition             : dedicated
         RETRY pulse                   : SCK
         serial program mode           : yes
         parallel program mode         : yes
         Timeout                       : 0
         StabDelay                     : 0
         CmdexeDelay                   : 0
         SyncLoops                     : 0
         ByteDelay                     : 0
         PollIndex                     : 0
         PollValue                     : 0x00
         Memory Detail                 :

                                  Block Poll               Page                       Polled
           Memory Type Mode Delay Size  Indx Paged  Size   Size #Pages MinW  MaxW   ReadBack
           ----------- ---- ----- ----- ---- ------ ------ ---- ------ ----- ----- ---------
           signature      0     0     0    0 no          3    0      0     0     0 0x00 0x00
           prodsig        0     0     0    0 no         61   61      0     0     0 0x00 0x00
           fuses          0     0     0    0 no          9   10      0     0     0 0x00 0x00
           fuse0          0     0     0    0 no          1    0      0     0     0 0x00 0x00
           fuse1          0     0     0    0 no          1    0      0     0     0 0x00 0x00
           fuse2          0     0     0    0 no          1    0      0     0     0 0x00 0x00
           fuse4          0     0     0    0 no          1    0      0     0     0 0x00 0x00
           fuse5          0     0     0    0 no          1    0      0     0     0 0x00 0x00
           fuse6          0     0     0    0 no          1    0      0     0     0 0x00 0x00
           fuse7          0     0     0    0 no          1    0      0     0     0 0x00 0x00
           fuse8          0     0     0    0 no          1    0      0     0     0 0x00 0x00
           lock           0     0     0    0 no          1    0      0     0     0 0x00 0x00
           data           0     0     0    0 no          0    0      0     0     0 0x00 0x00
           usersig        0     0     0    0 no         32   32      0     0     0 0x00 0x00
           flash          0     0     0    0 no      16384   64      0     0     0 0x00 0x00
           eeprom         0     0     0    0 no        256   32      0     0     0 0x00 0x00

         Programmer Type : JTAGICE3_UPDI
         Description     : Atmel AVR XplainedMini in UPDI mode
         ICE hardware version: 0
         ICE firmware version: 1.19 (rel. 57)
         Serial number   : MICROUPDIPROGRAMMERX
         Vtarget         : 3.30 V
         JTAG clock megaAVR/program: 0 kHz
         JTAG clock megaAVR/debug:   0 kHz
         JTAG clock Xmega: 0 kHz
         PDI clock Xmega : 0 kHz

avrdude: Short read, read only 0 out of 64 bytes
avrdude: jtag3_edbg_recv(): Unexpected response 0x18
avrdude: retrying with external reset applied
avrdude: jtag3_edbg_send(): Unexpected response 0x81, 0x11
avrdude: jtag3_edbg_recv(): Unexpected response 0x80
avrdude: retrying with external reset applied
avrdude: JTAGEN fuse disabled?
avrdude: initialization failed, rc=-1
         Double check connections and try again, or use -F to override
         this check.

avrdude: jtag3_edbg_send(): Unexpected response 0x81, 0x11
avrdude: jtag3_edbg_recv(): Unexpected response 0x80
avrdude: jtag3_edbg_send(): Unexpected response 0x81, 0x11
avrdude: jtag3_edbg_recv(): Unexpected response 0x80
avrdude: jtag3_edbg_signoff(): unexpected response 0x81, 0x11
avrdude: jtag3_edbg_signoff(): unexpected response 0x01, 0x00

avrdude done.  Thank you.

Failed programming: uploading error: exit status 1```

seems that initialization has failed on the attiny1616, and i read a little (and understood even less) about the combination reset/updi pin on the attiny1616 and how there might be some kind of internal fuse i need to set or something to allow for programs to be uploaded?

again im new to UPDI uploading and im not sure if there is like a reset window to program the attiny1616, or if i need to add a resistor to ground on one of the pins etc. OR if its even a problem with the attiny1616, my custom board not being soldered correctly (despite my inspection) or if the microUPDI programmer has some kind of error. is there any resistors i need to set on the microUPDI after uploading the UPDI firmware to the pro micro?

thanks in advance for any help

MCUdude, 2023-07-04:
I see you're using megaTinyCore, which bundles an outdated Avrdude (6.3) version with many bugs that were later resolved.

In order to figure out if you're facing a hardware issue, or if it's simply Avrdude 6.3 that doesn't work that well with the microUPDI, you should download Avrdude 7.1 from here:

https://github.com/arduino/avrdude-packing/releases/tag/7.1-arduino.1

Extract the archive, and run the following command (where you insert the path to the avrdude.conf file that came with Avrdude 7.1, and the path to the hex file you want to upload):

```
avrdude.exe -C /path/to/avrdude.conf -c xplainedmini_updi -U flash:w:path/to/file.hex
```

Sk8rSeth, 2023-07-04:
thanks for the quick reply. this command actually returns its own set of errors
```avrdude error: invalid file format '\Users\Mjolnir\Desktop\Projects\TestCode\TestCode.hex' in update specifier
avrdude
error: unable to parse update operation 'flash:w:C:\Users\Mjolnir\Desktop\Projects\TestCode\TestCode.hex'```

i got the hex file by using `Sketch > Export Compiled Binary` from the Arduino IDE 1.8.19. i am assuming im using the avrdude command improperly but --help did not provide much on the command.

is there a way for me to replace the outdated avrdude version within megaTinyCore so i can try to upload from the IDE directly? im not familiar with the command line version of avrdude and im having a hard time finding documentation about the flags and commands.

MCUdude, 2023-07-04:
> this command actually returns its own set of errors

Try adding quotes around the path to the hex file, and add the `:i` at the end (meaning Intel hex file format)

`-U flash:w:"flash:w:"C:\Users\Mjolnir\Desktop\Projects\TestCode\TestCode.hex":i`

> Is there a way for me to replace the outdated avrdude version within megaTinyCore so i can try to upload from the IDE directly?

It's possible to replace the Avrdude binary megaTinyCore uses, and the avrdude.conf file, but if you can't figure it out, you can still use Avrdude directly without having to "export compiled binary" every time. Turn on verbose compilation and upload under the IDE settings, and you'll find the full path to where the compiled hex file is located after a successful compilation.

Avrdude 7.2 will soon be released, with a bunch of new features and improvements over 7.1, and especially over 6.3. Spence, the megaTinyCore maintainer, has said that he will update from 6.3 to 7.2 as soon as the release is ready.

Sk8rSeth, 2023-07-04:
Ah thank you, the quotes and the explicit intel format were the problem there. but i am getting the same problem as before:
failed to initialize. im not sure if this is a hardware error with this attiny1616 or something else. when it fails to initialize, do you know its trying to do? im wondering if my circuit might have a resistor blocking a reset pulse (or not blocking when it should) or something like that?

full error from the command line upload:

``` avrdude error: initialization failed, rc=-1
        - double check the connections and try again
        - use -B to set lower ISP clock frequency, e.g. -B 125kHz
        - use -F to override this check

avrdude done.  Thank you.```

MCUdude, 2023-07-04:
Can you post the complete Avrdude 7.1 output, but this time, add `-v` at the end? This enables verbose output, which _may_ reveal something

Sk8rSeth, 2023-07-04:
absolutely
```
avrdude: Version 7.1
         Copyright the AVRDUDE authors;
         see https://github.com/avrdudes/avrdude/blob/main/AUTHORS

         System wide configuration file is C:\Users\Mjolnir\Downloads\avrdude_Windows_32bit\etc\avrdude.conf

         Using Port                    : usb
         Using Programmer              : xplainedmini_updi
avrdude: found CMSIS-DAP compliant device, using EDBG protocol
         AVR Part                      : ATtiny1616
         RESET disposition             : dedicated
         RETRY pulse                   : SCK
         Serial program mode           : yes
         Parallel program mode         : yes
         Memory Detail                 :
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
MCUdude, 2023-07-04:
> absolutely

Thank you! However, the verbose output doesn't reveal much more useful information. If you have a multimeter of some sort, can you check that there is a 330 ohm resistor between the UPDI pin on the 6-pin connector, and digital pin 7 on your Arduino Pro Micro?

> I am noticing that avrdude is specifying 3.3v with vTarget, but my system and attiny1616 are designed for 5v. the microUPDI is also using the 5v jumper. could that be the problem?

Most likely not. The Xplained Mini/microUPDI can't read the target voltage, and it doesn't care about it either. It runs at 5V no matter what. I'm not sure why the microUPDI firmware reports 3.3V, as I don't have the source code (only Microchip has, and they won't share it).

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

Sk8rSeth, 2023-07-04:
classic Microchip, not caring about open source work lol

my multimeter reads 331 ohm between those two pins, so i think its safe to say the resistor is in place.

i am starting to think it must be a problem with my circuit. im using the VQFN package of the attiny, so maybe there is a trace bridged underneath that i can visibly see.

Sk8rSeth, 2023-07-04:
> This may be it. I've used an ATtiny1616 in a VQFN package myself, and I had to reflow it twice + do some rework to get it to work as it should.

thats good to know, ill give this package more scrutiny. is this the kind of problem that one might see with a poorly reflowed QFN package? this is the first one ive used so im not sure how problems manifest with them yet

MCUdude, 2023-07-04:
My problem was that the chip "floated" on top of the solder, where some pads made contact while others didn't

Sk8rSeth, 2023-07-04:
thank you for all your help! glad to know the microUPDI is all good to go!

Closed 2023-07-24.

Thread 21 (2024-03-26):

Outdated readme?

larsfagerbakke, 2024-03-26:
I tried to follow the instructions (https://github.com/MCUdude/microUPDI), but I'm having some issues.

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

Getting board info ARduino IDE states unknown board. Looking at the device registry in Windows "bus reported device description" states "mEDBG CDC", so I think I managed to make programmer out of my nano (?).

I've downloaded megaTinyCore but there is on Onboard Atmel mEDBG option. Are you able to update your documentation?

MCUdude, 2024-03-31:
Hi, and sorry for the late reply. I've been on "påskeferie", but I'm back home now.

> Getting board info ARduino IDE states unknown board.

> I've downloaded megaTinyCore but there is on Onboard Atmel mEDBG option. Are you able to update your documentation?

I'll assume you meant _no_ Onboard Atmel mEDBG option? The correct programmer option should be `Xplained Mini (mEDBG, debug chip: ATmega32u4)` when using megaTinyCore.

Closed 2024-11-17.

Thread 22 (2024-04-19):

I'm stuck. Unable to flash the Arduino Pro Micro as microUPDI programmer

jaccobezemer, 2024-04-19:
Hello,

I have a working Pro Micro. Uploaded the Pro Micro Test Code and I get blinking LEDs.

When I select microUPDI Firmware Uploader from the boards menu and click the upload button I get an error.

```
FQBN: microUPDIcore:avr:microupdi
Using board 'microupdi' from platform in folder: C:\Users\jacco\AppData\Local\Arduino15\packages\microUPDIcore\hardware\avr\1.0.2
Using core 'arduino' from platform in folder: C:\Users\jacco\AppData\Local\Arduino15\packages\arduino\hardware\avr\1.8.6

Detecting libraries used...
C:\Users\jacco\AppData\Local\Arduino15\packages\microUPDIcore\hardware\avr\1.0.2/scripts/dummy-preproc-macros-command.bat C:\Users\jacco\AppData\Local\Temp\arduino\sketches\AE9949AC16C921D4D53471318DBE9348/preproc ctags_target_for_gcc_minus_e.cpp
Error while detecting libraries included by C:\Users\jacco\AppData\Local\Temp\arduino\sketches\AE9949AC16C921D4D53471318DBE9348\sketch\sketch_apr19a.ino.cpp
Generating function prototypes...
C:\Users\jacco\AppData\Local\Arduino15\packages\microUPDIcore\hardware\avr\1.0.2/scripts/dummy-preproc-macros-command.bat C:\Users\jacco\AppData\Local\Temp\arduino\sketches\AE9949AC16C921D4D53471318DBE9348/preproc ctags_target_for_gcc_minus_e.cpp
The system cannot find the path specified.
exit status 1

Compilation error: exit status 1
```

What path can't be found? What am I missing?

jaccobezemer, 2024-04-20:
So I still don't know why I get the error.
But I managed to upload the firmware using a modified version of scripts\CLI flash script\Load_firmware.bat and a Arduino UNO as Arduino ISP.
It looks like a got a working microUPDI programmer as I managed to upload firmware to an ATMega4809.

MCUdude, 2024-04-20:
Hi!
Sorry for the late reply! Great to hear you managed to upload the firmware through the alternative script provided. I'll try to look into why you weren't able to upload the firmware using the IDE.

Closed 2024-04-20.

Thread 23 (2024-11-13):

Wrong / static target showing up in MP Lab X

platima, 2024-11-13:
Great work - purchased from your Tindie store, and using for my DeepSleepr project!

Oddly though, in MP Lab X the kit comes up as having a ATmega4809 connected - it's actually on an Attiny414.

Having dug through https://github.com/MCUdude/microUPDIcore I cannot find reason for this.

When I try to use it as a tool, overriding the device detection, it just loops forever trying to update the mEDBG firmware;

```
Currently loaded versions:
Application version...........1.19.57 (0x01.0x13.0x39)
Tool pack version .............1.2.438
Entering firmware upgrade mode
```

Any ideas? Cheers

MCUdude, 2024-11-14:
The mEDBG firmware is actually designed to be used with a ready-made kit. The firmware the MicroUPDI programmer uses was pulled from a board that used an ATmega4809. If you want to change this you can connect an ISP programmer to it and inspect it's EEPROM content. I'm the EE memory somewhere the 3-byte ATmega4809 signature that's in there can be replaced with the ATtiny414 if you like.

platima, 2024-11-14:
Ah yep excellent - will look for that signature.

Any idea about MP Lab IDE X trying to upgrade the mEDBG firmware in loop? I am thinking I might just try to find that hex version info and match it.

MCUdude, 2024-11-14:
I don't think it will try to update the firmware, as it is the latest. And the Micro UPDI uses a different bootloader, (avr109 instead of DFU), so it won't succeed anyways.

platima, 2024-11-14:
That's what I would have thought too! Long story short microUPDI appears to boot fine, shows up as 'miniUPDI' in the X IDE kits. I enable Tools -> Options -> Embedded -> "Exclude device checks for kits" else it complains about it being a 4809.

Then when I try to flash my 414 with it, it compiles the code, then pops up with a new window. The microUPDI reboots into bootloader mode (all LEDs on) and the window repeats the following forever:
```
Currently loaded versions:
Application version...........1.19.57 (0x01.0x13.0x39)
Tool pack version .............1.2.438
Entering firmware upgrade mode
```

Checking MCC Content Manager, 1.2.438 is the version of the mEDBG Support Kit installed, so it appears to be trying to up/downgrade 1.19.57 as it detects on the programmer to what it has. The only other kit version available are 1.1.105 or 1.0.11.

Absolutely stumped! Using my jtag2updi instead again, but obviously I'd prefer to use this - hence paying for it hah. Also on that note, just let me know if you want me to stock it at https://shop.plati.ma 😊

Welcoming any input, and thanks again!

mraardvark, 2024-11-15:
One thing you could try to do to prevent MPLAB from updating the firmware:
set an environment variable: _JAVA_OPTIONS to -Dgen4.disable.updates=true
No idea if it works for mEDBG, but worth a try

platima, 2024-11-16:
Could not find any option for that!

Worked on the hex files for a while, managed to get it to see an "ATmega4149" haha, but could not get the version string changed to match. Then instead tried the other option; made an mEDBG Pack for MPLABX that matched the version strings and didn't include upgrade files. That ALMOST worked, but;
`Failed to get Device ID. Please make sure the target device is attached and try the operation again.`

Full log
[debugtool.txt](https://github.com/user-attachments/files/17782991/debugtool.txt)

And I'm stumped again. Confirmed it's definitely set to UPDI mode, 0.5MHz, no high voltage.

MCUdude, 2024-11-16:
If you want to study the mEDBG/microUPDI EEPROM content, the developers revealed a few secrets here:
https://www.avrfreaks.net/s/topic/a5C3l000000UkjBEAS/t192342?comment=P-1635680

> Want me to issue a PR with a copy of the MP Lab X IDE 6.20 pack so others can use your wonderful little tool with it?

Thanks, but I'm already working on updating the firmware. I also need to modify the hex file so so you won't have to physically connect the AREF pin to VCC.

MCUdude, 2024-11-16:
I just pushed a new firmware version. Try installing microUPDIcore manually, force-enter bootloader mode on your microUPDI programmer and see if it does the trick. Works fine here with MPLAB X!

platima, 2024-11-16:
Hey thanks for that link - just modified the EEP file to show a 414. Attached if ever needed.

Is it just your firmware that's updated, or the EEPROM too?[
[mEDBG_UPDI_1.13_ATtiny414.eep.zip](https://github.com/user-attachments/files/17788156/mEDBG_UPDI_1.13_ATtiny414.eep.zip)

platima, 2024-11-16:
Yep okay board name shows up as "microUPDI programmer" after flashing with new FW.

Any notable changes? Your commit just said version update 😅

platima, 2024-11-16:
Confirmed works perfectly IN MPLAB X IDE 6.20 without requiring custom pack (default of 'use latest' works fine).

Thank you kindly good sir

MCUdude, 2024-11-16:
I did write a short summary of which changes where done in this commit.

https://github.com/MCUdude/microUPDIcore/commit/cf361357a9963a89c9a26753d5d09b104e91119b

The new firmware probably doesn't matter all that much, other than making MPLAB X happy. I'll do a proper boards manager release soon

platima, 2024-11-16:
Great stuff, that's hugely appreciated.

As mentioned, if you want to stock your programmer in my shop just let me know. Seems like a lot of people make good use of it!

Either way, back to working on DeepSleepr with better debugging now 😊 Cheers!

platima, 2024-11-16:
Found a new issue, but I don't think it's on your end - build and program for production; works fine. Build and program for debug, and it never completes programming. Hangs forever. Both this new and the previous hex & EEPROM seem to do it though, so probably something in MPLAB X I need to address

MCUdude, 2024-11-16:
> As mentioned, if you want to stock your programmer in my shop just let me know. Seems like a lot of people make good use of it!

Thanks for the offer, but I'm quite happy with Tindie. I don't make and sell boards to make a whole lot of money, I do it because I enjoy tinkering in the evenings. And at the moment I'm fine with the current "pace" where I ship a programmer or two every now and then.

> Found a new issue, but I don't think it's on your end - build and program for production; works fine. Build and program for debug, and it never completes programming. Hangs forever. Both this new and the previous hex & EEPROM seem to do it though, so probably something in MPLAB X I need to address

Sounds like an MPLAB X problem indeed! And if there was a bug in the mEDBG firmware, it would be next to impossible to fix it, because the firmware is closed source.

platima, 2024-11-16:
> I don't make and sell boards to make a whole lot of money, I do it because I enjoy tinkering in the evenings

I fully get that - that's why I started the shop (excess goods hah) and make the YouTube videos. Still yet to take any money back out of it, but enjoying it and building up a broader range of products.

Okay yeah fair - time to headbutt MPLAB X for a while hah.

platima, 2024-11-16:
Oddly I've just found it's the microUPDI programmer that is having some odd issue. If I build & program for production, it stays connected, but if I build & program for debug, the COM port disappears. I can confirm that the target was successfully put into download mode though. Very odd!

MCUdude, 2024-11-17:
> EDIT: I'm a spud. My code goes straight into a sleep mode. Of course that does not debug 😅

Great to hear you figured it out! A new release of microUPDIcore is now available through boards manager (v1.0.3), so I'm closing this. I've also added [documentation regarding the EEPROM content](https://github.com/MCUdude/microUPDI?tab=readme-ov-file#tinkering-with-the-eeprom-content) and how to modify it.

Closed 2024-11-17.

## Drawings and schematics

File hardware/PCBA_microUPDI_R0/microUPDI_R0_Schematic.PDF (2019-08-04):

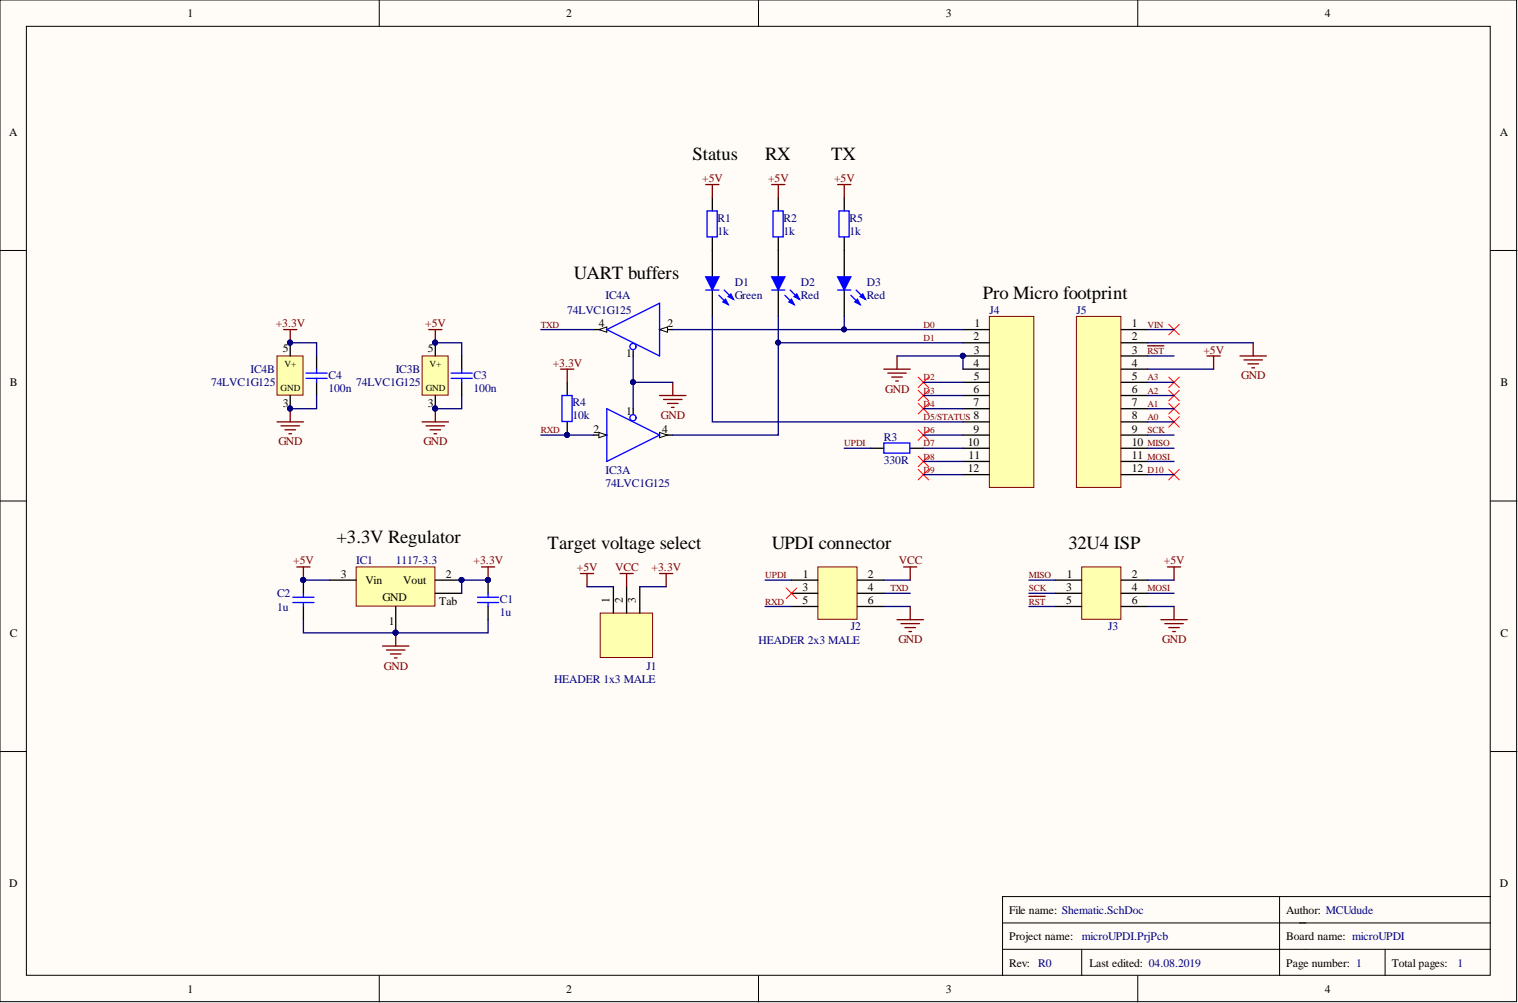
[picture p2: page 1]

D0
D1 | 2

File name: Shematic.SchDoc | Author: MCUdude

Project name: microUPDI.PrjPcb | Board name: microUPDI

Rev: R0 | Last edited: 04.08.2019 | Page number: 1 | Total pages: 1

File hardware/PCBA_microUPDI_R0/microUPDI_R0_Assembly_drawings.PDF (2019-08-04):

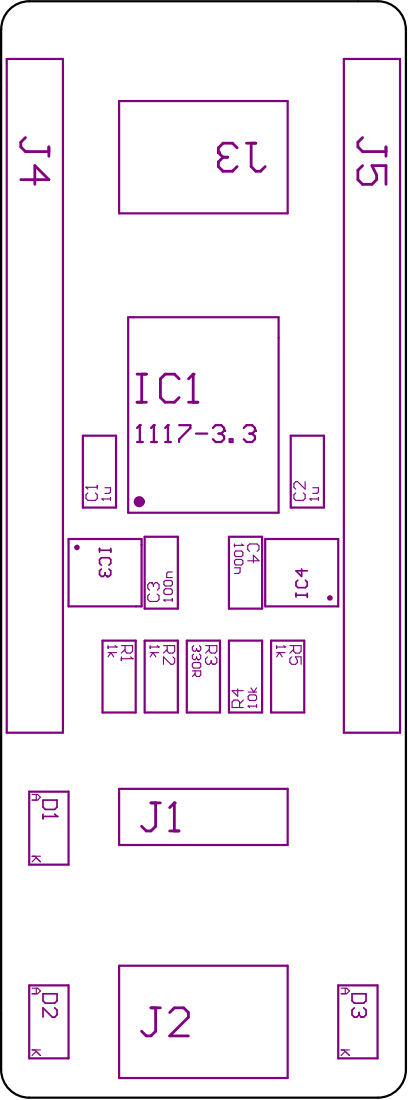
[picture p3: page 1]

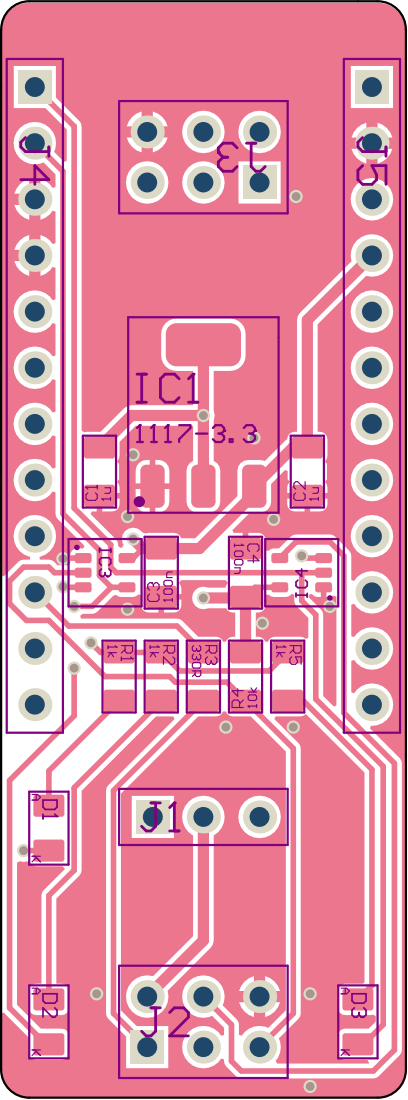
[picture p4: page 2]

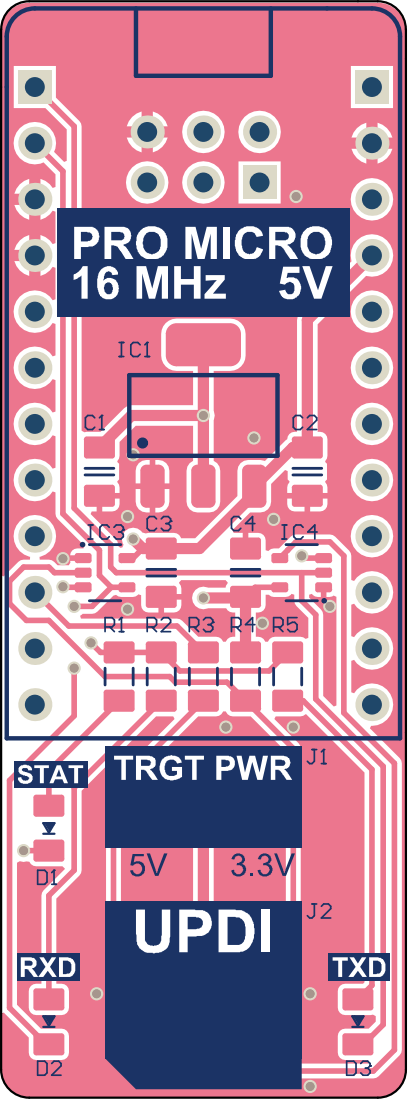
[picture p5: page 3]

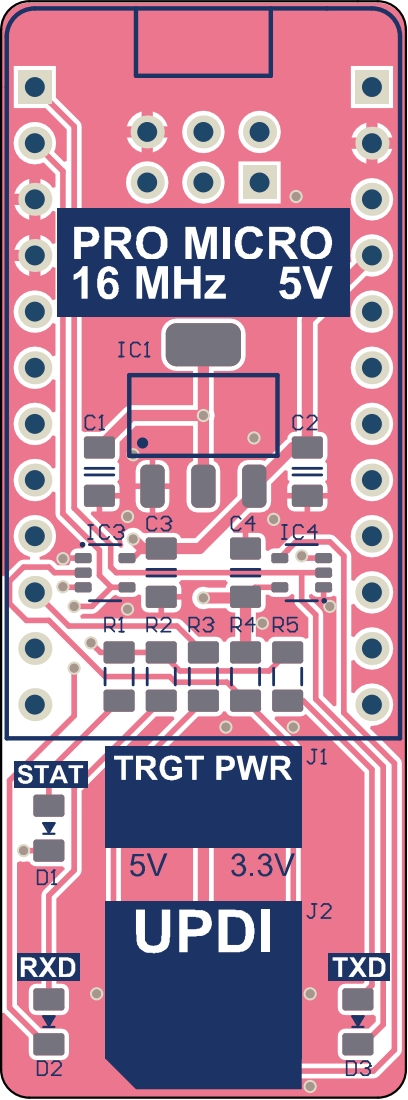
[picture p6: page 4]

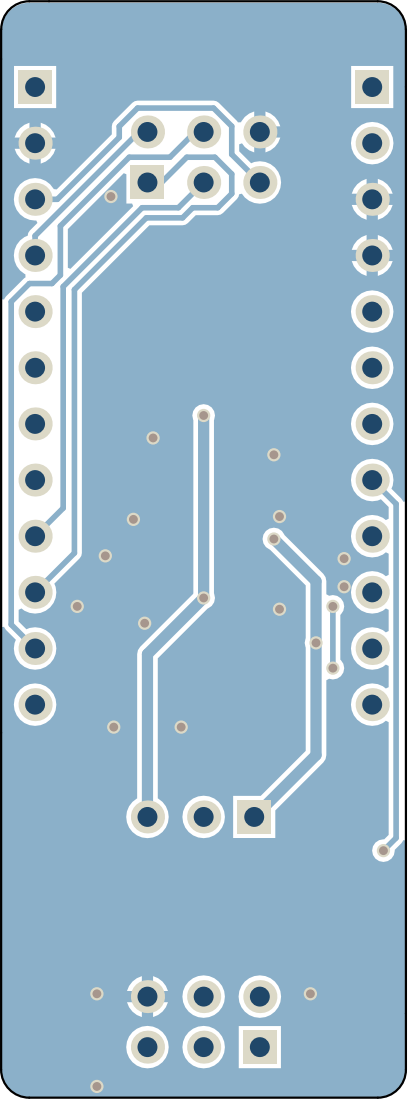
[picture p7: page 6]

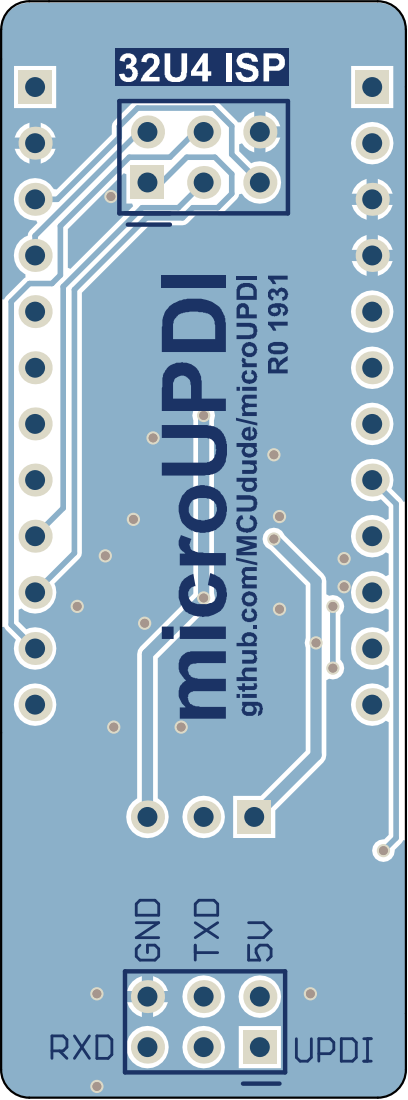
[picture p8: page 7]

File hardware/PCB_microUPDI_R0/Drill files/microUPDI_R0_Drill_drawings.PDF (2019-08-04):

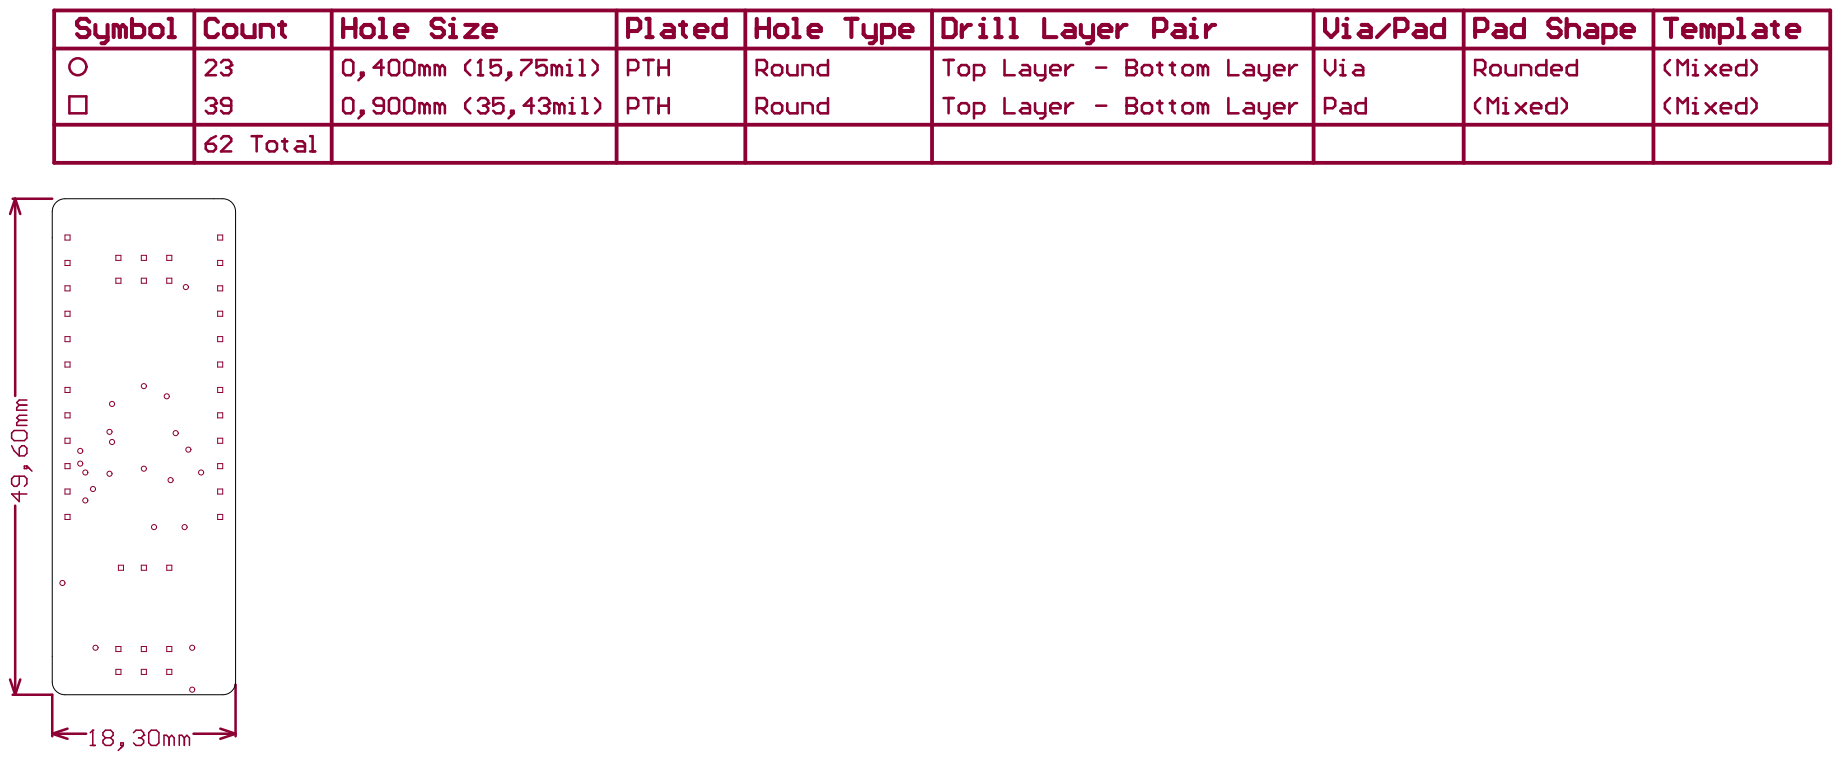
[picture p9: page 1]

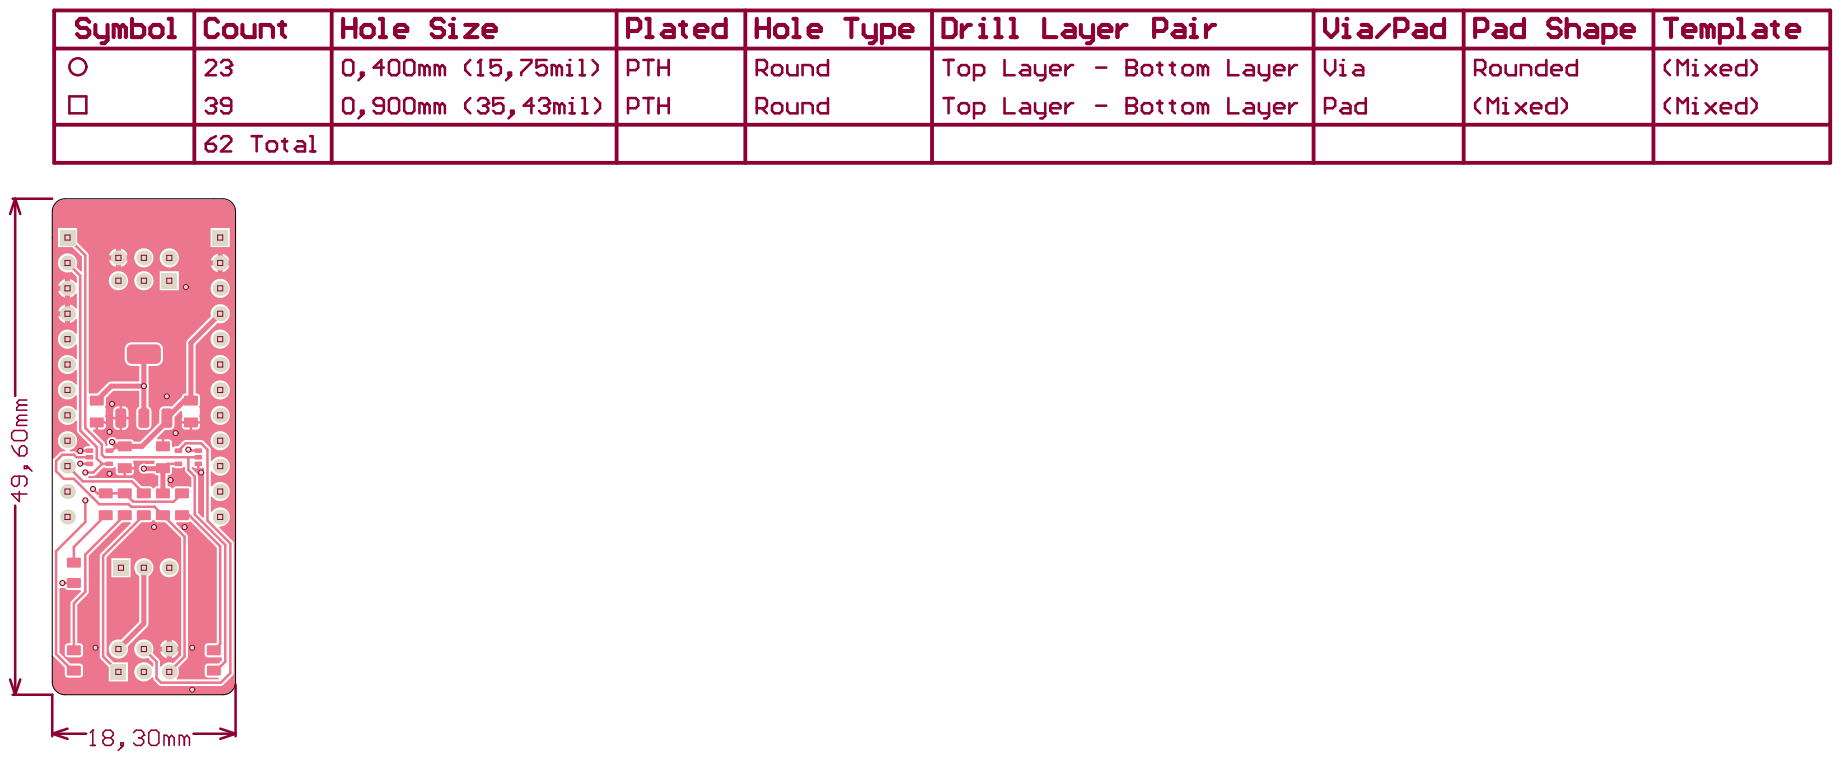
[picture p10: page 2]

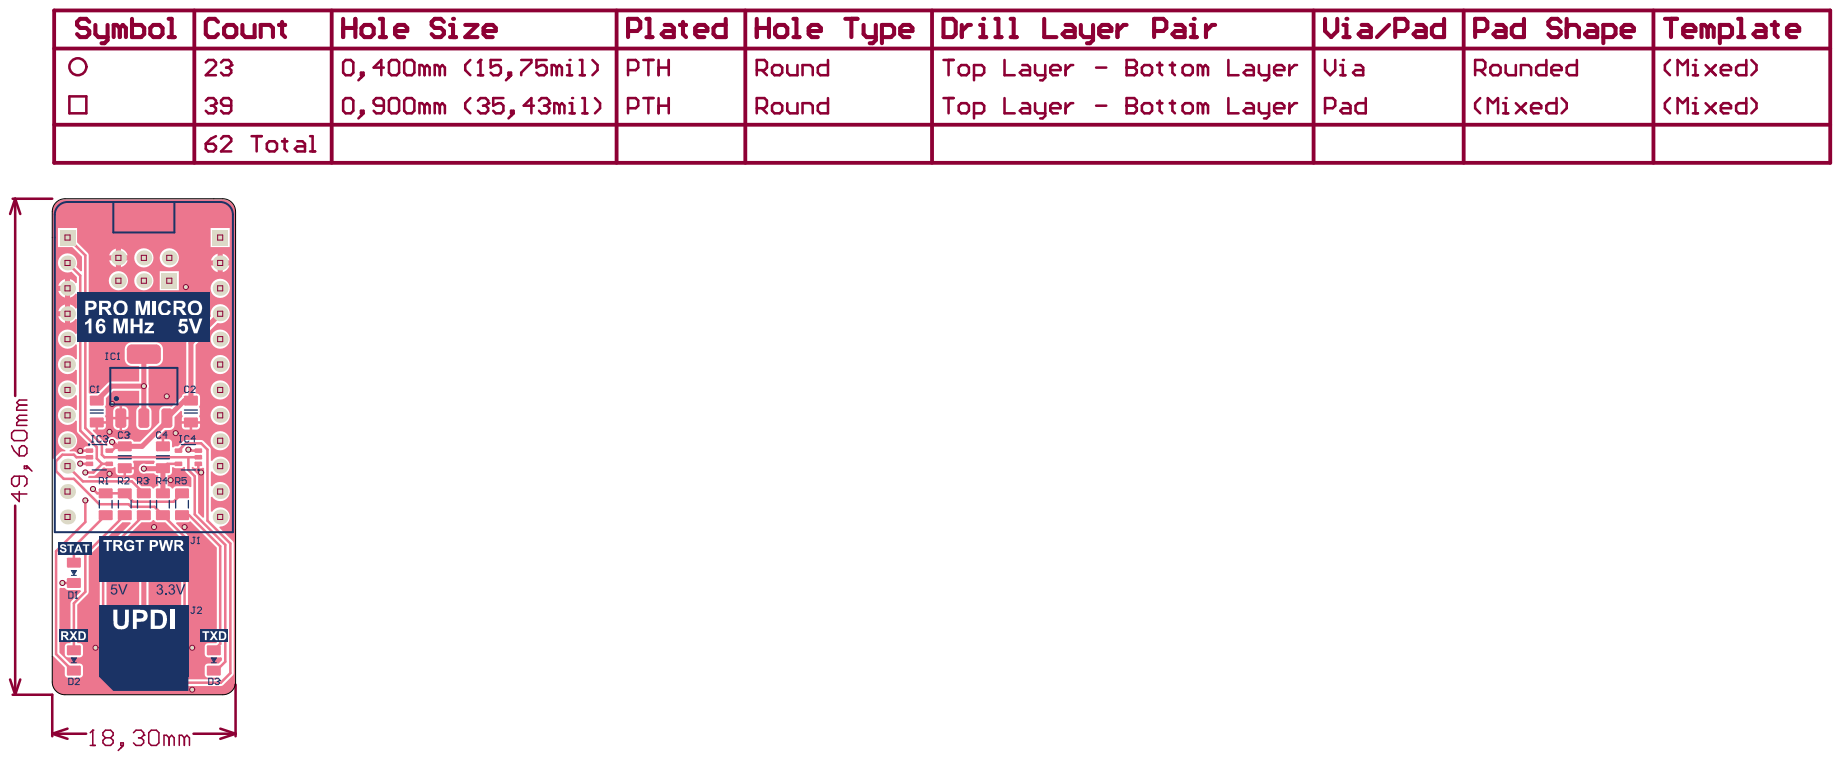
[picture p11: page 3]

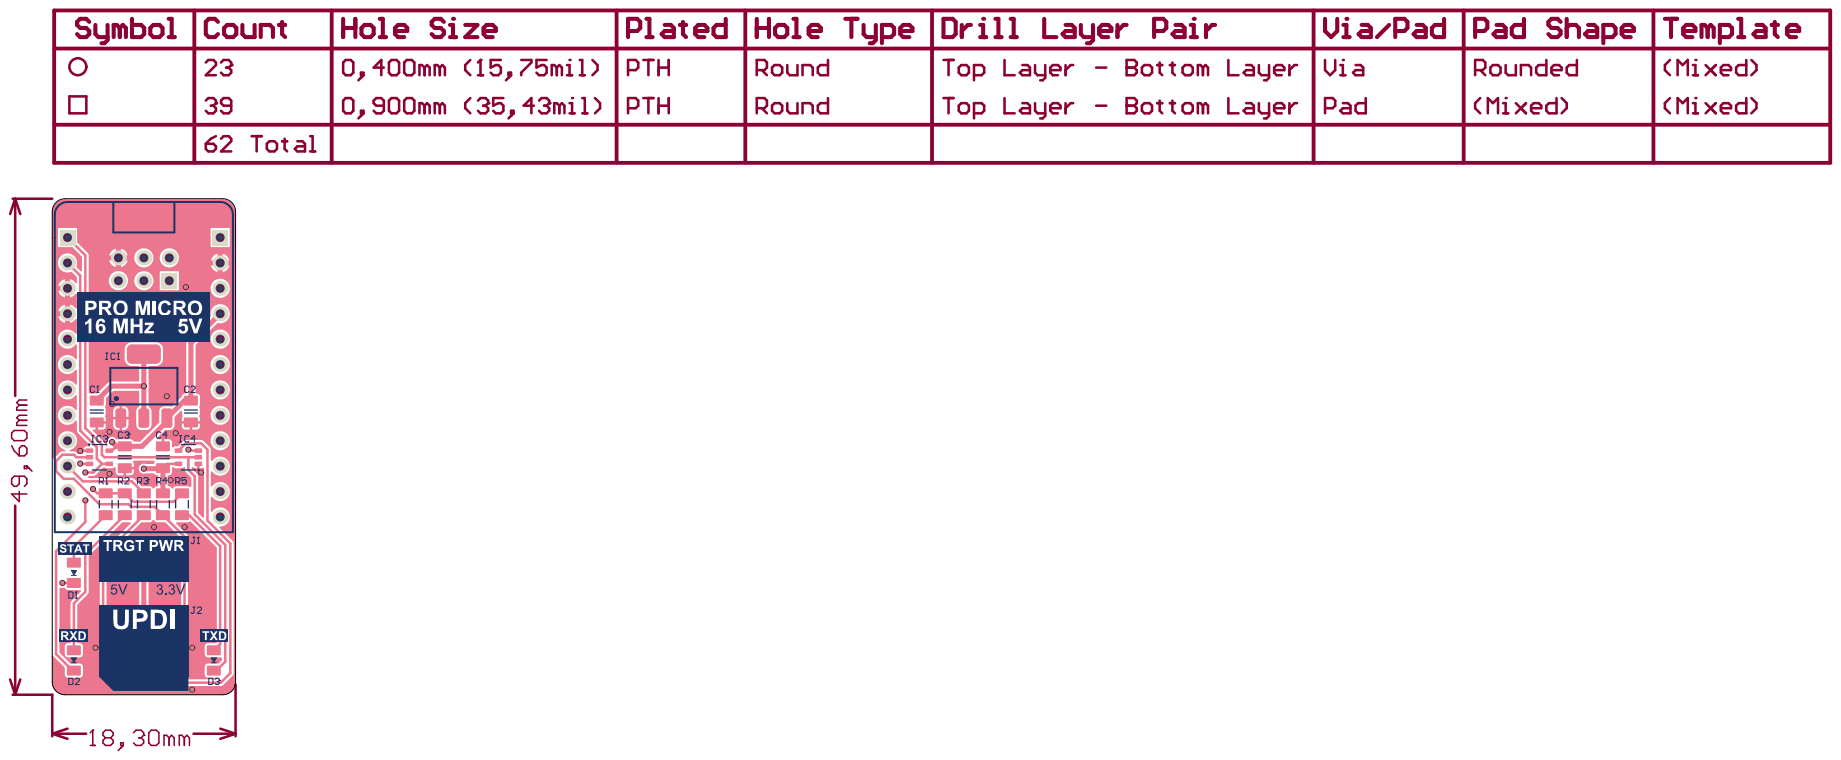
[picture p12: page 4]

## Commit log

2019-08-04 Add hardware files
    [PCB.PcbDoc, Shematic.SchDoc, microUPDI.PrjPcb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]
2019-08-05 Remove firmware files Moved to a separate repository https://github.com/MCUdude/microUPDIcore for better Arduino IDE integration
